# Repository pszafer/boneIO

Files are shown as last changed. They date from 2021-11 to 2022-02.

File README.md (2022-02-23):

# Project description

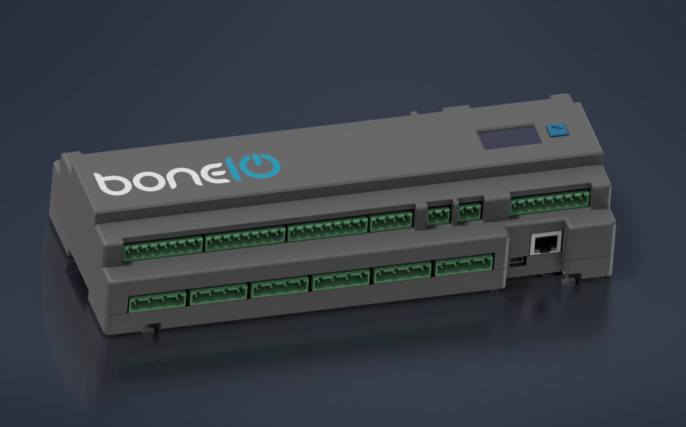
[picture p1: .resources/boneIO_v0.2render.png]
BonePic


`BoneIO` is a compact IO controller for home automation. Main features of this controller are

- Compact size (27x11x6)cm - 15 DIN modules
- DIN rail compatibility
- Low price
- Open HSP (See below)

## Whole documentation you will find here: https://boneio.eu/

## Case, Circuit and Code was moved into separate repositories. You can find it here: https://github.com/boneIO-eu

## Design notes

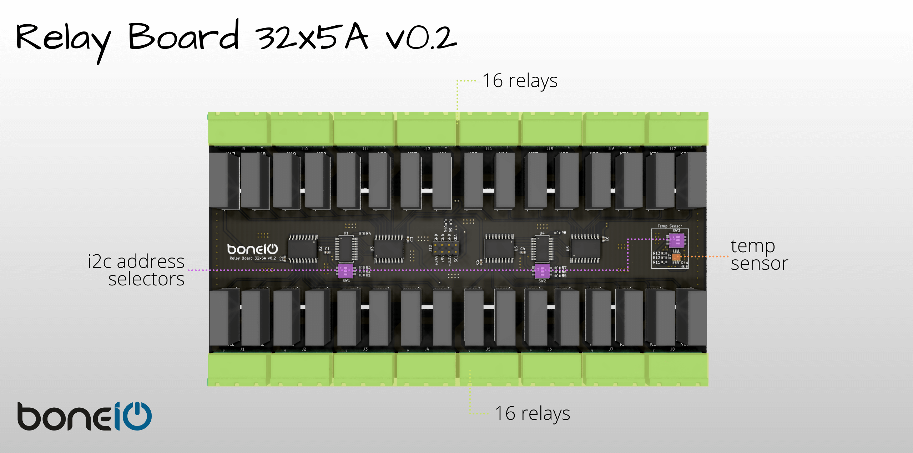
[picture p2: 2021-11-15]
.resources/relay_board_32x5A_text.png

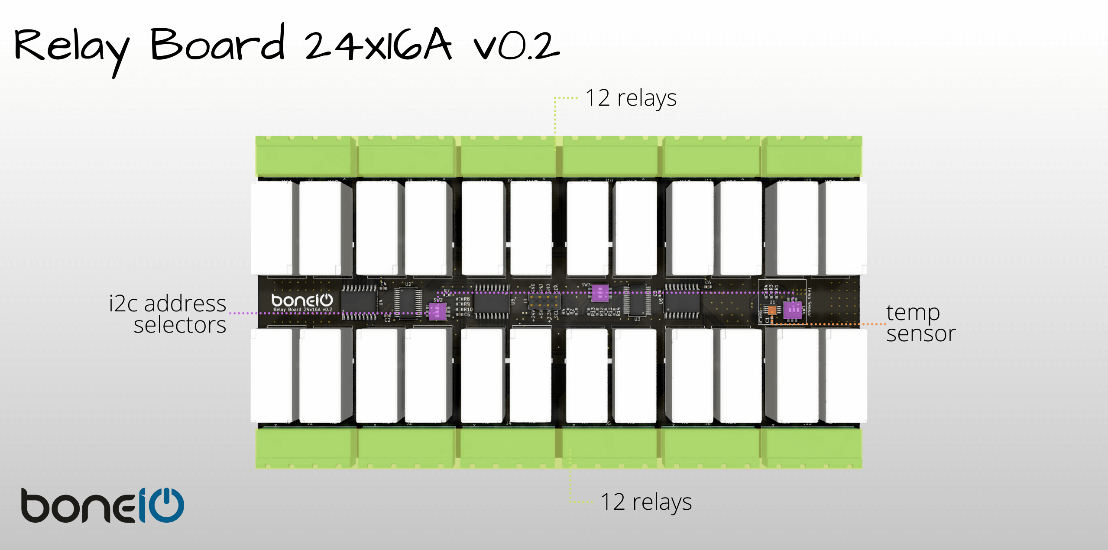
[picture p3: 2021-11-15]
.resources/relay_board_24x16A_text.png

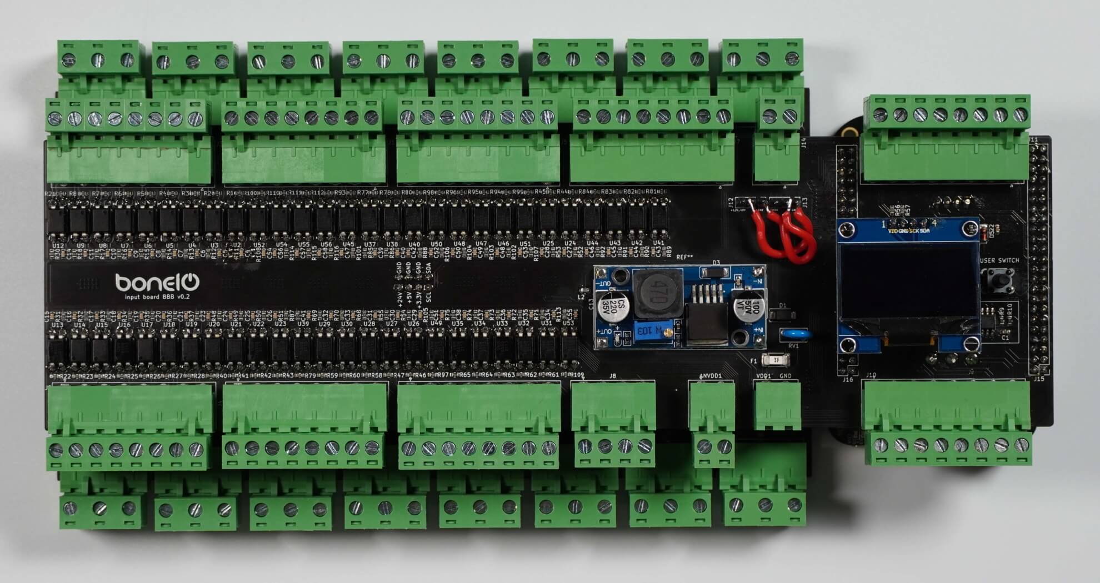
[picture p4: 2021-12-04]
.resources/boneIO_v0.2_full_without_case.jpg

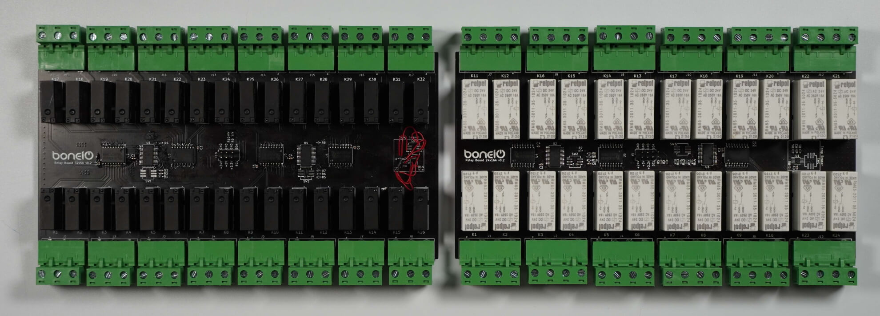
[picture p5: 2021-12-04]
.resources/boneIO_v0.2_relays.jpg

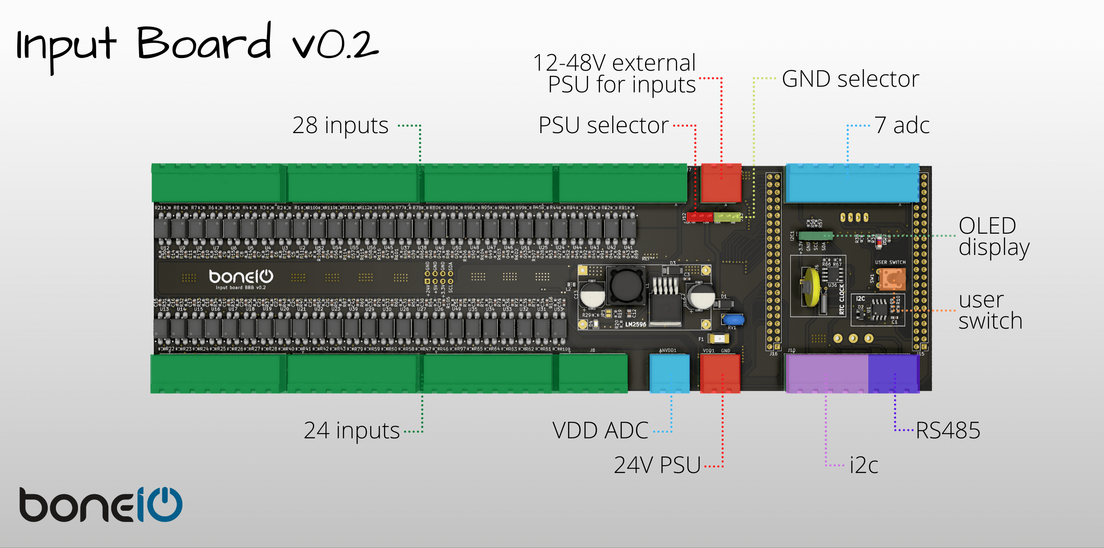
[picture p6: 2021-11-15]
.resources/input_board_text.png

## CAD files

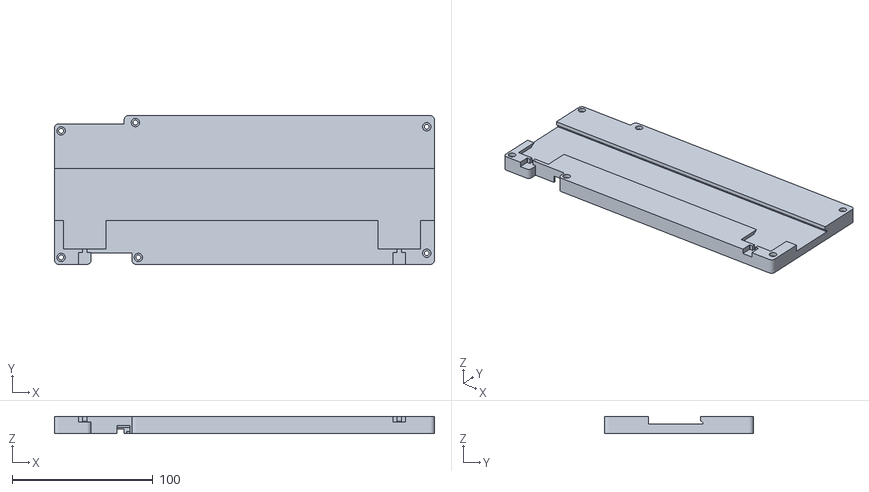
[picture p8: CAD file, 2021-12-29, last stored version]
Case/case_back.stl
270.0 x 105.8 x 12.3

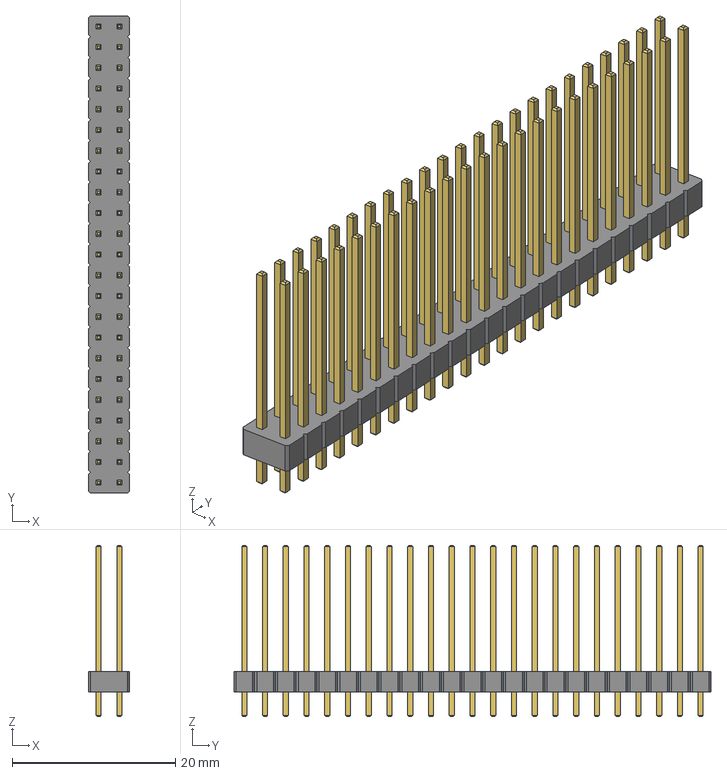
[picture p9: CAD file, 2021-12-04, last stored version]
Circuit/boneIO - input board_BBB/3D_model/46_pin.stp
5.08 x 58.4 x 21.0 mm

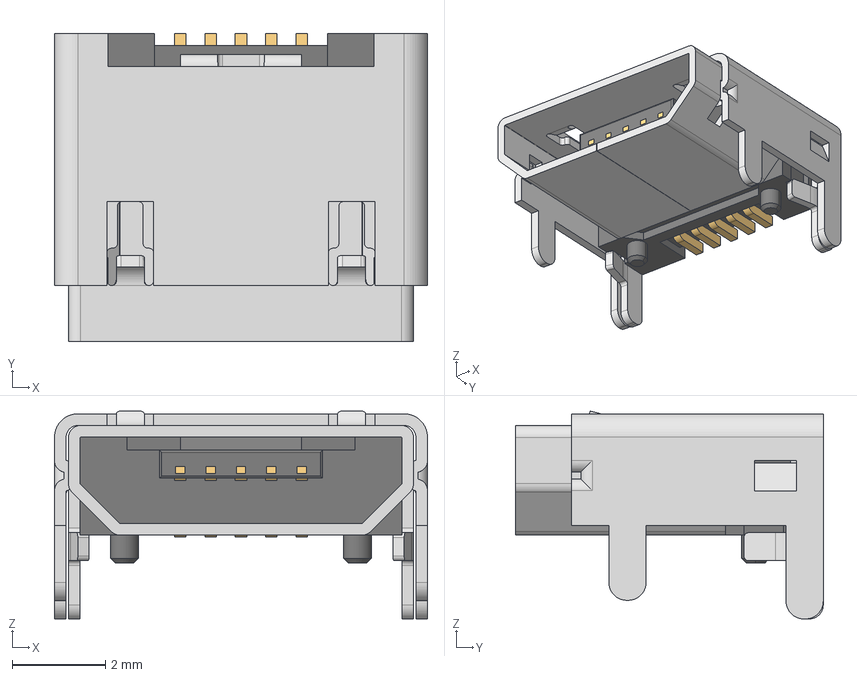
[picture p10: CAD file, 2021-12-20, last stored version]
Circuit/boneIO - input board_ESP/3D/usb_micro_4p.stp
8.00 x 6.60 x 4.46 mm

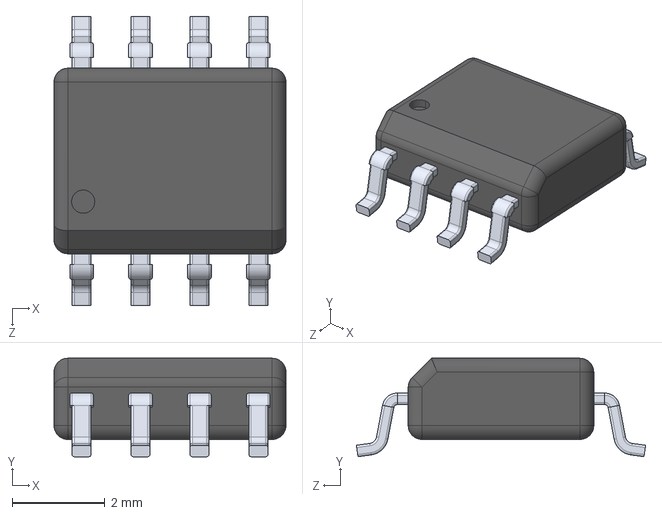
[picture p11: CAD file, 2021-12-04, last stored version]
Circuit/boneIO - relay board 24x10A/3D_model/SO8.STEP
5.00 x 2.12 x 6.23 mm

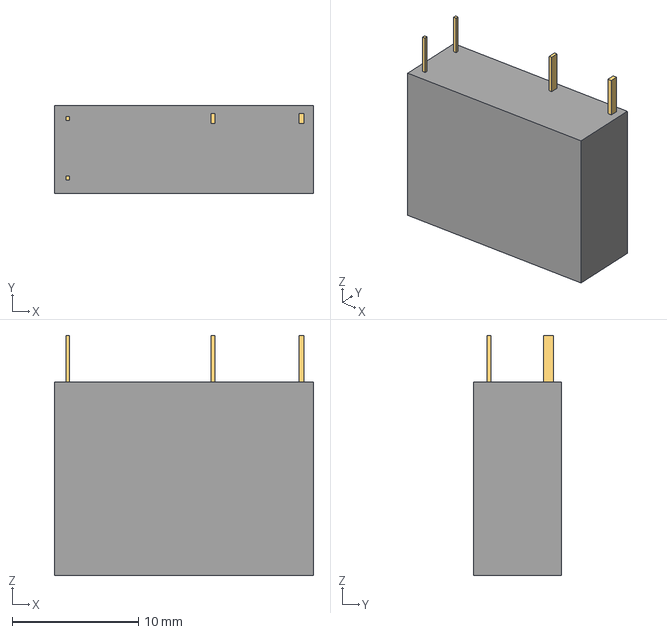
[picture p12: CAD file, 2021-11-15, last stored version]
Circuit/boneIO - relay board 32x5A/HF46/HF46F.step
20.5 x 7.00 x 19.0 mm

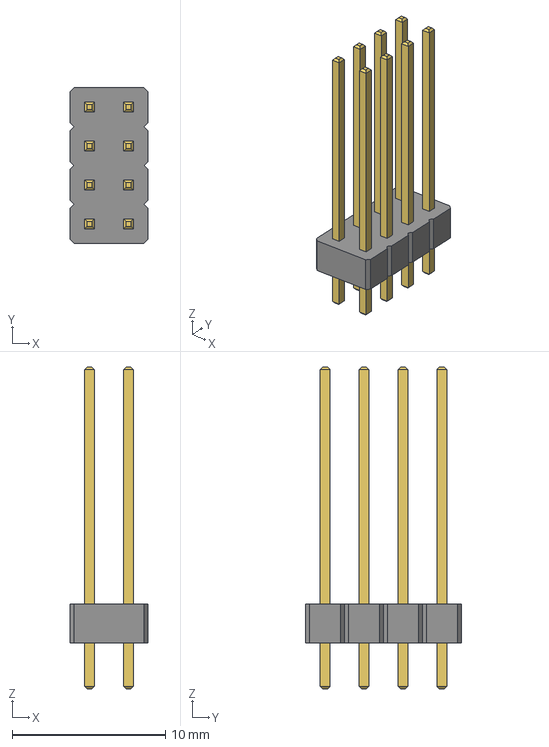
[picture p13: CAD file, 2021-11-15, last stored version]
Circuit/boneIO - relay board 32x5A/PH80DS-21/PH80DS-21.stp
5.08 x 10.2 x 21.0 mm

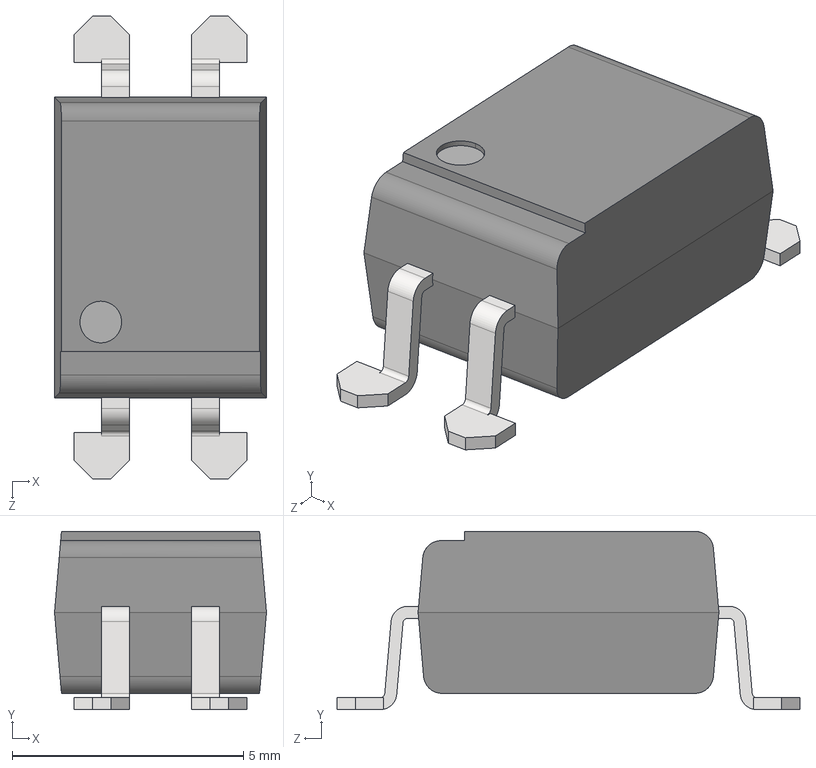
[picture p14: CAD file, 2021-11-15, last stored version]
Circuit/boneIO - shield input board v0.2/3D_model/PC817.STEP
4.58 x 3.85 x 10.0 mm
PC817 Body
Gullwing Pin
Gullwing Pin_MIR
Gullwing Pin_MIR1
Gullwing Pin_MIR_MIR

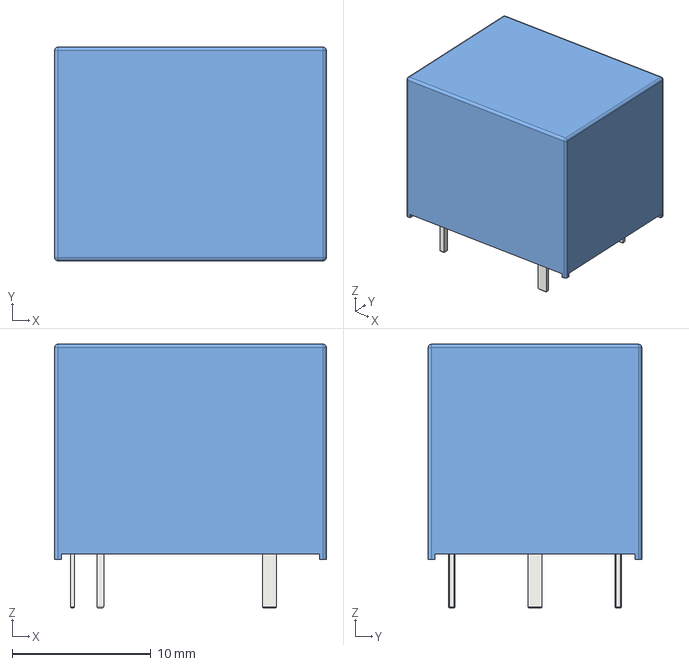
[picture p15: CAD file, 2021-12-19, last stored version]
Circuit/boneIO - shutter board 32x10A/3d_Model/Relay_SPDT_SANYOU_SRD_Series_Form_C.step
19.6 x 15.4 x 19.0 mm

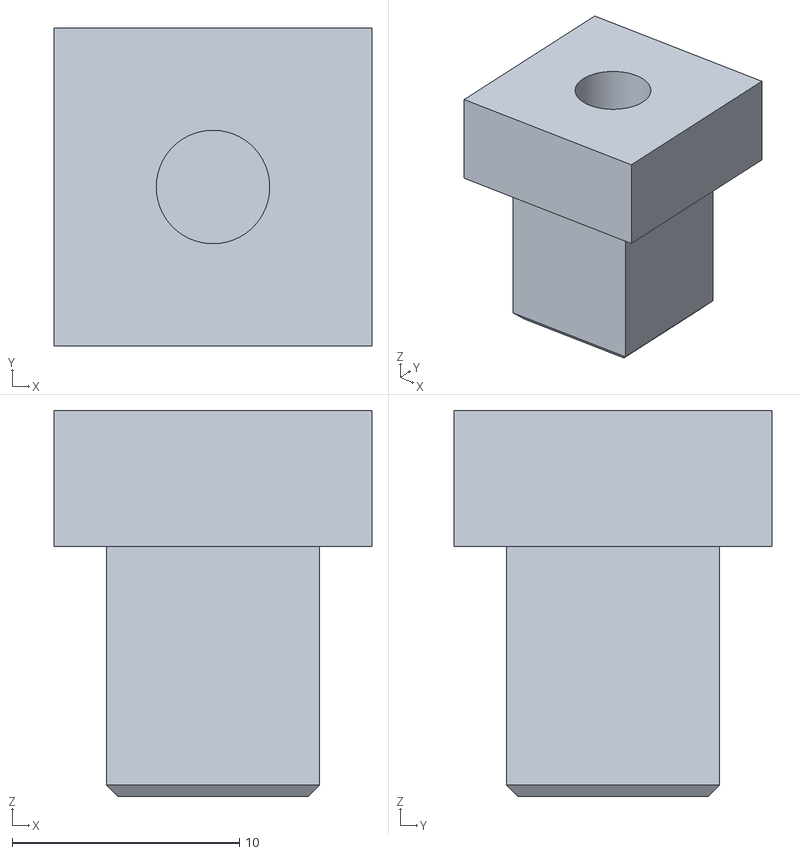
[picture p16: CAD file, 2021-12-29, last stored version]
Case/button.stl
14.0 x 14.0 x 17.0

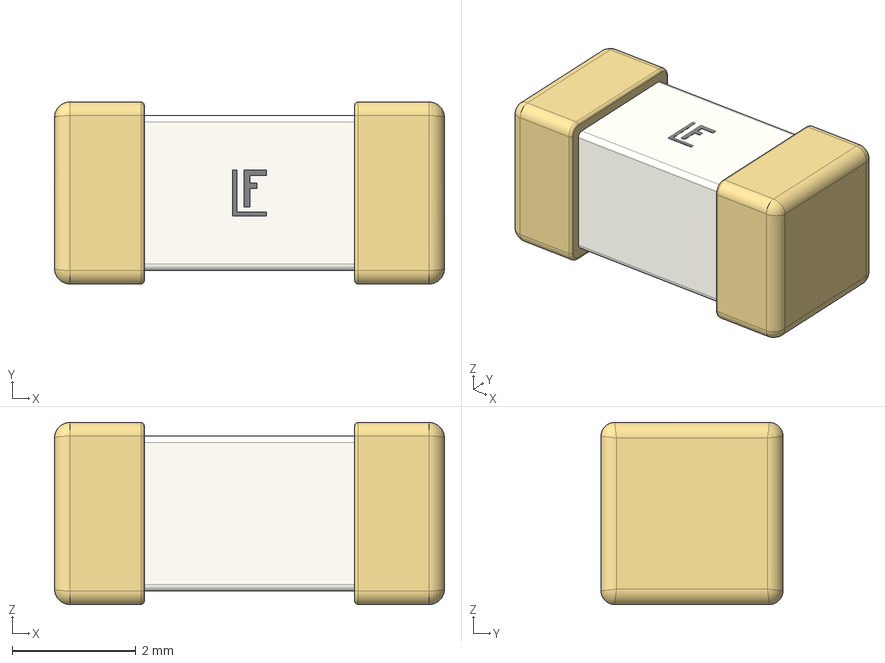
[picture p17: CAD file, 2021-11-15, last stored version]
Circuit/boneIO - input board_BBB/3D_model/FUSE LTL-451.stp
6.30 x 2.94 x 2.94 mm

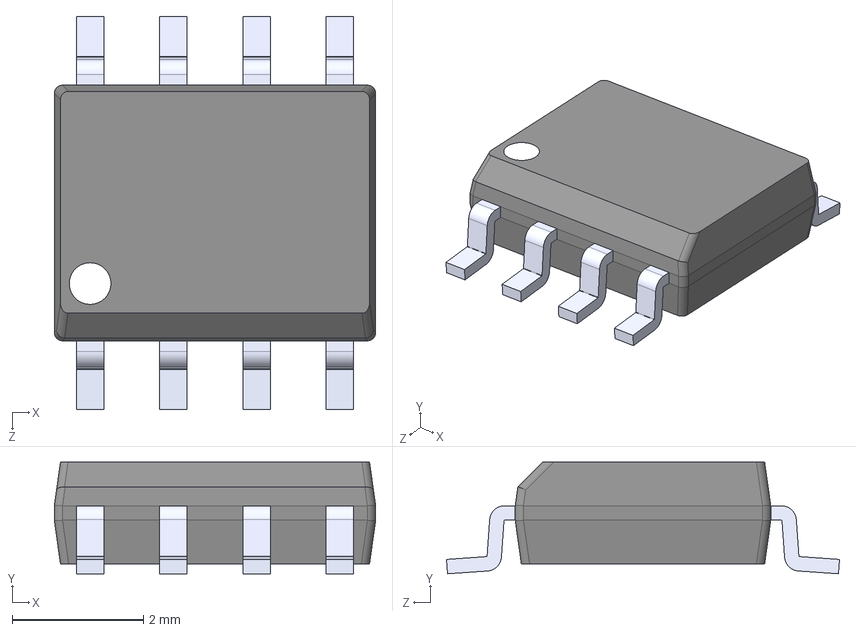
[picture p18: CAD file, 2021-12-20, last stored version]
Circuit/boneIO - input board_ESP/3D/MP1584EN.step
4.90 x 1.70 x 5.99 mm

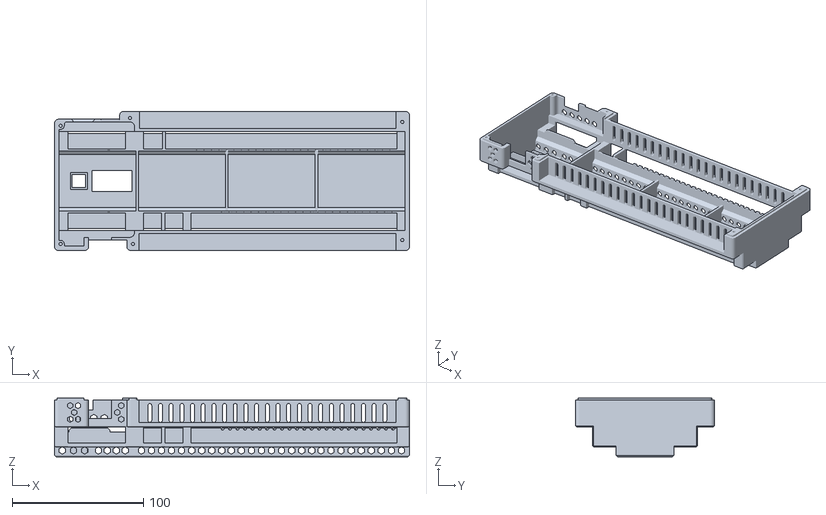
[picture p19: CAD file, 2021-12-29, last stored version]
Case/case_front.stl
270.0 x 105.8 x 44.5

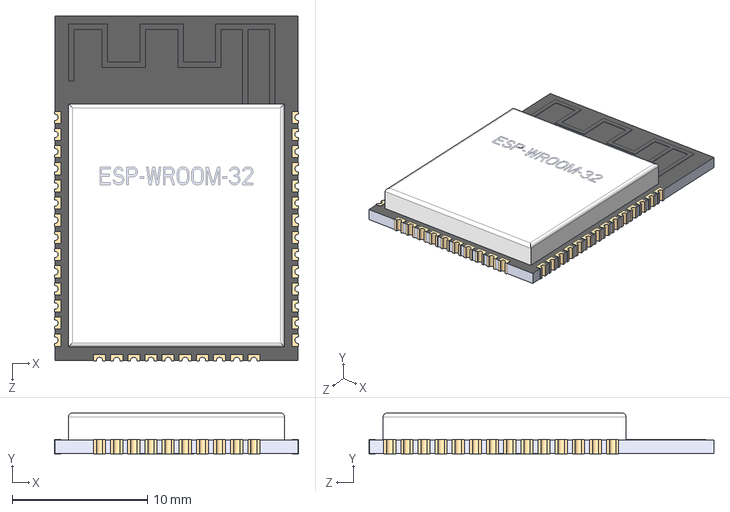
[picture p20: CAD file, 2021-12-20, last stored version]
Circuit/boneIO - input board_ESP/3D/esp-wroom-32.step
18.1 x 3.04 x 25.5 mm

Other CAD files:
Case/boneIO-bottom-clips.stl
Case/boneIO-button-distance-relay-24x16A.stp
Case/boneIO-button-distance-relay-32x5A.stp
Case/boneIO-button.stl
Case/boneIO-case-front.stl
Case/boneIO-case_back.stl
Case/boneIO-case_front.stl
Case/boneIO-distance-relay-24x16.stl
Case/boneIO-distance-relay-32x5.stl
Case/boneIO-lock-pin.stl
Case/clips.stl
Case/lock_pin.stl
Case/spacer_relay_24x16A.stl
Case/spacer_relay_32x5A.stl
Circuit/boneIO - input board/3D_model/CR1220_VCNK.stp
Circuit/boneIO - input board_BBB/3D_model/CR1220_VCNK.stp
Circuit/boneIO - input board_ESP/3D/Connector_1Port_RJ45.step
Circuit/boneIO - input board_ESP/3D/ESP32.STEP
Circuit/boneIO - relay board 24x10A/3D_model/RM852011351005_1.step
Circuit/boneIO - relay board 24x16A/3D_model/RM852011351005_1.step

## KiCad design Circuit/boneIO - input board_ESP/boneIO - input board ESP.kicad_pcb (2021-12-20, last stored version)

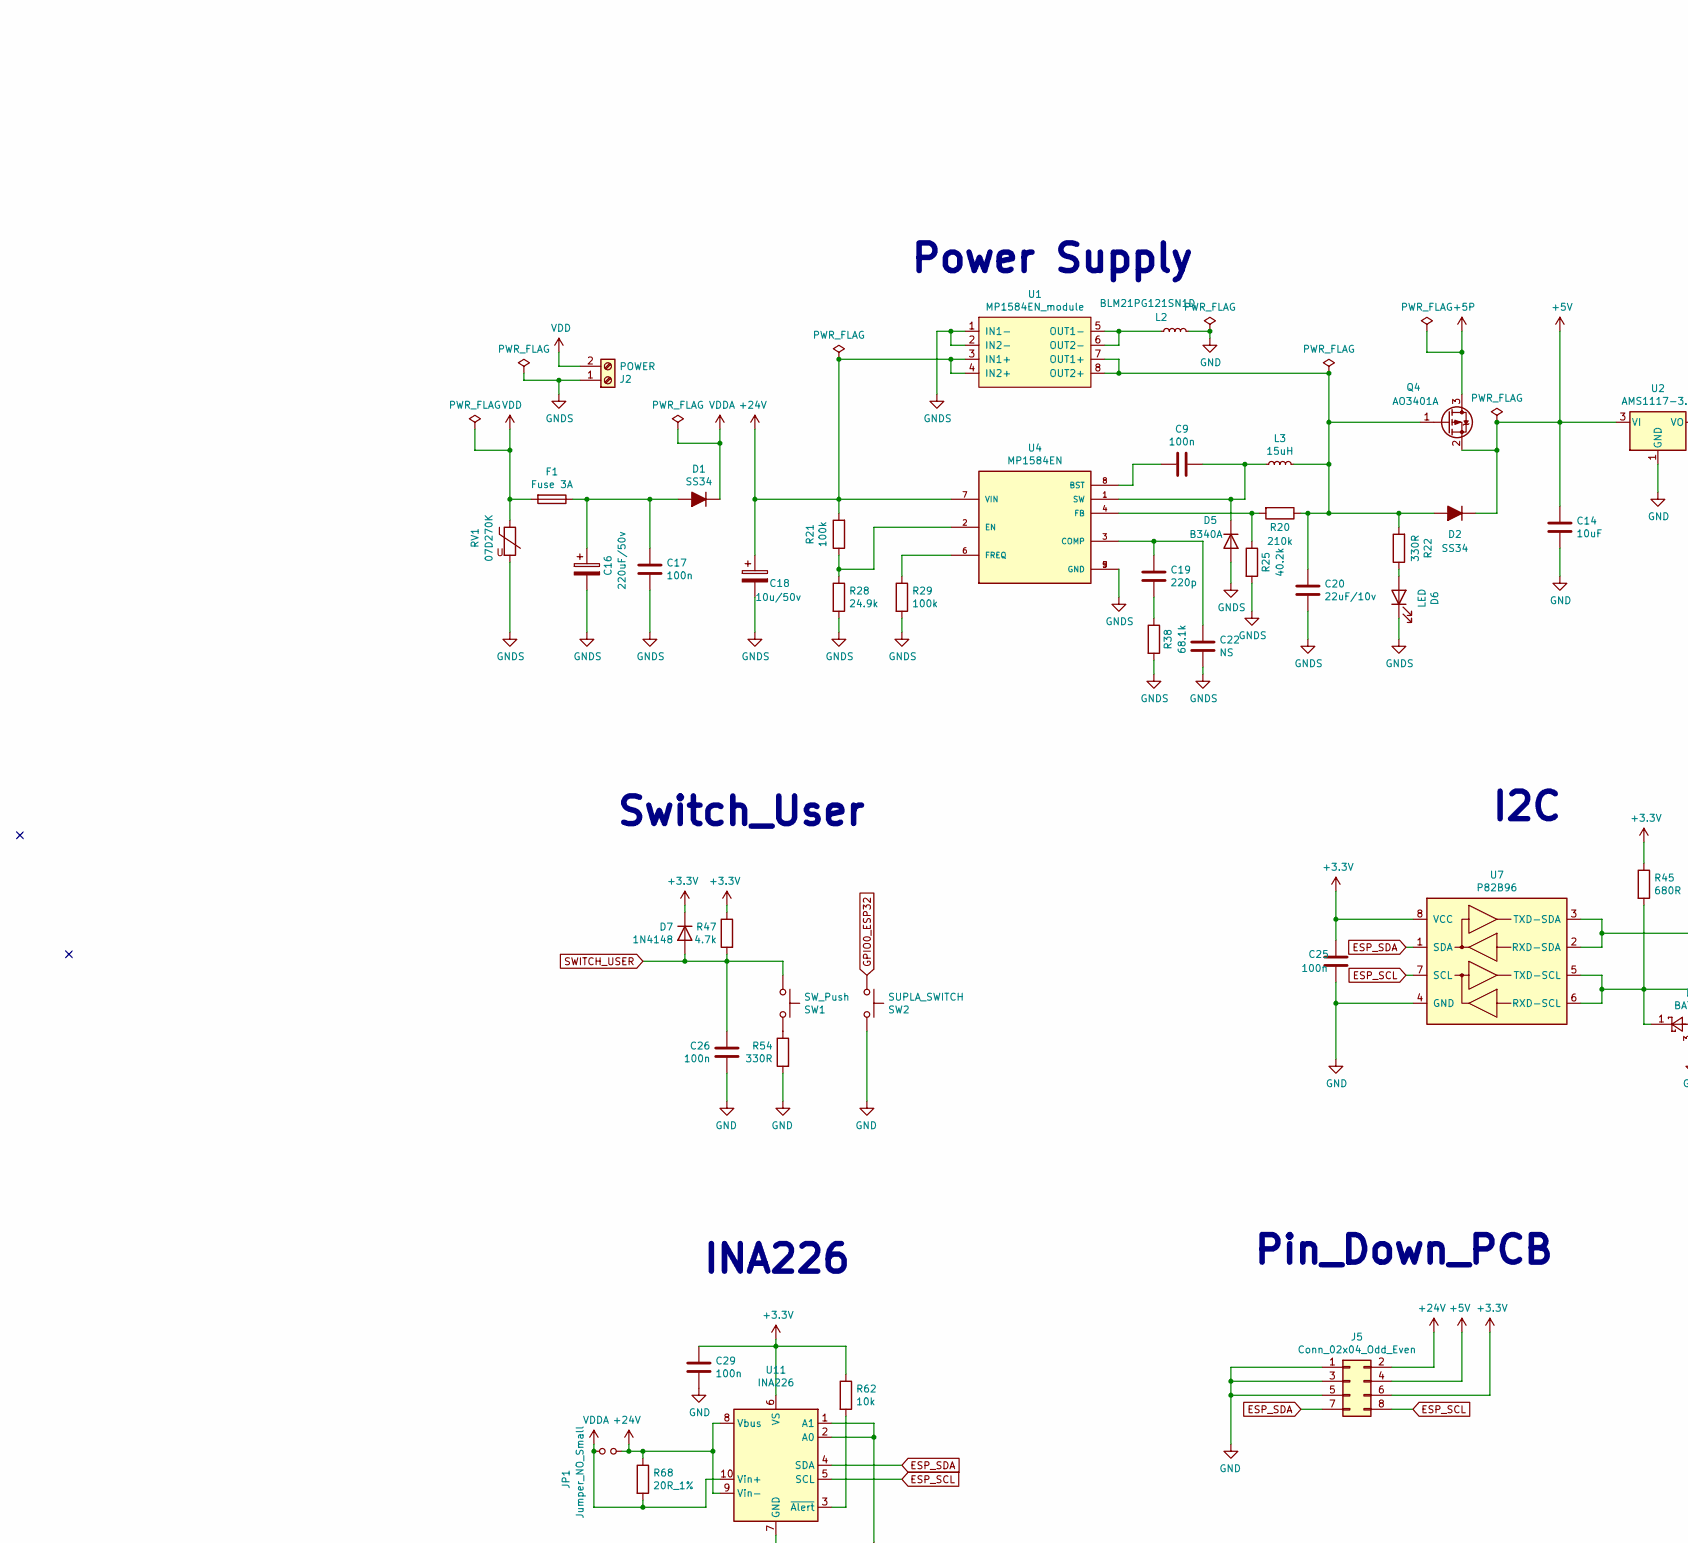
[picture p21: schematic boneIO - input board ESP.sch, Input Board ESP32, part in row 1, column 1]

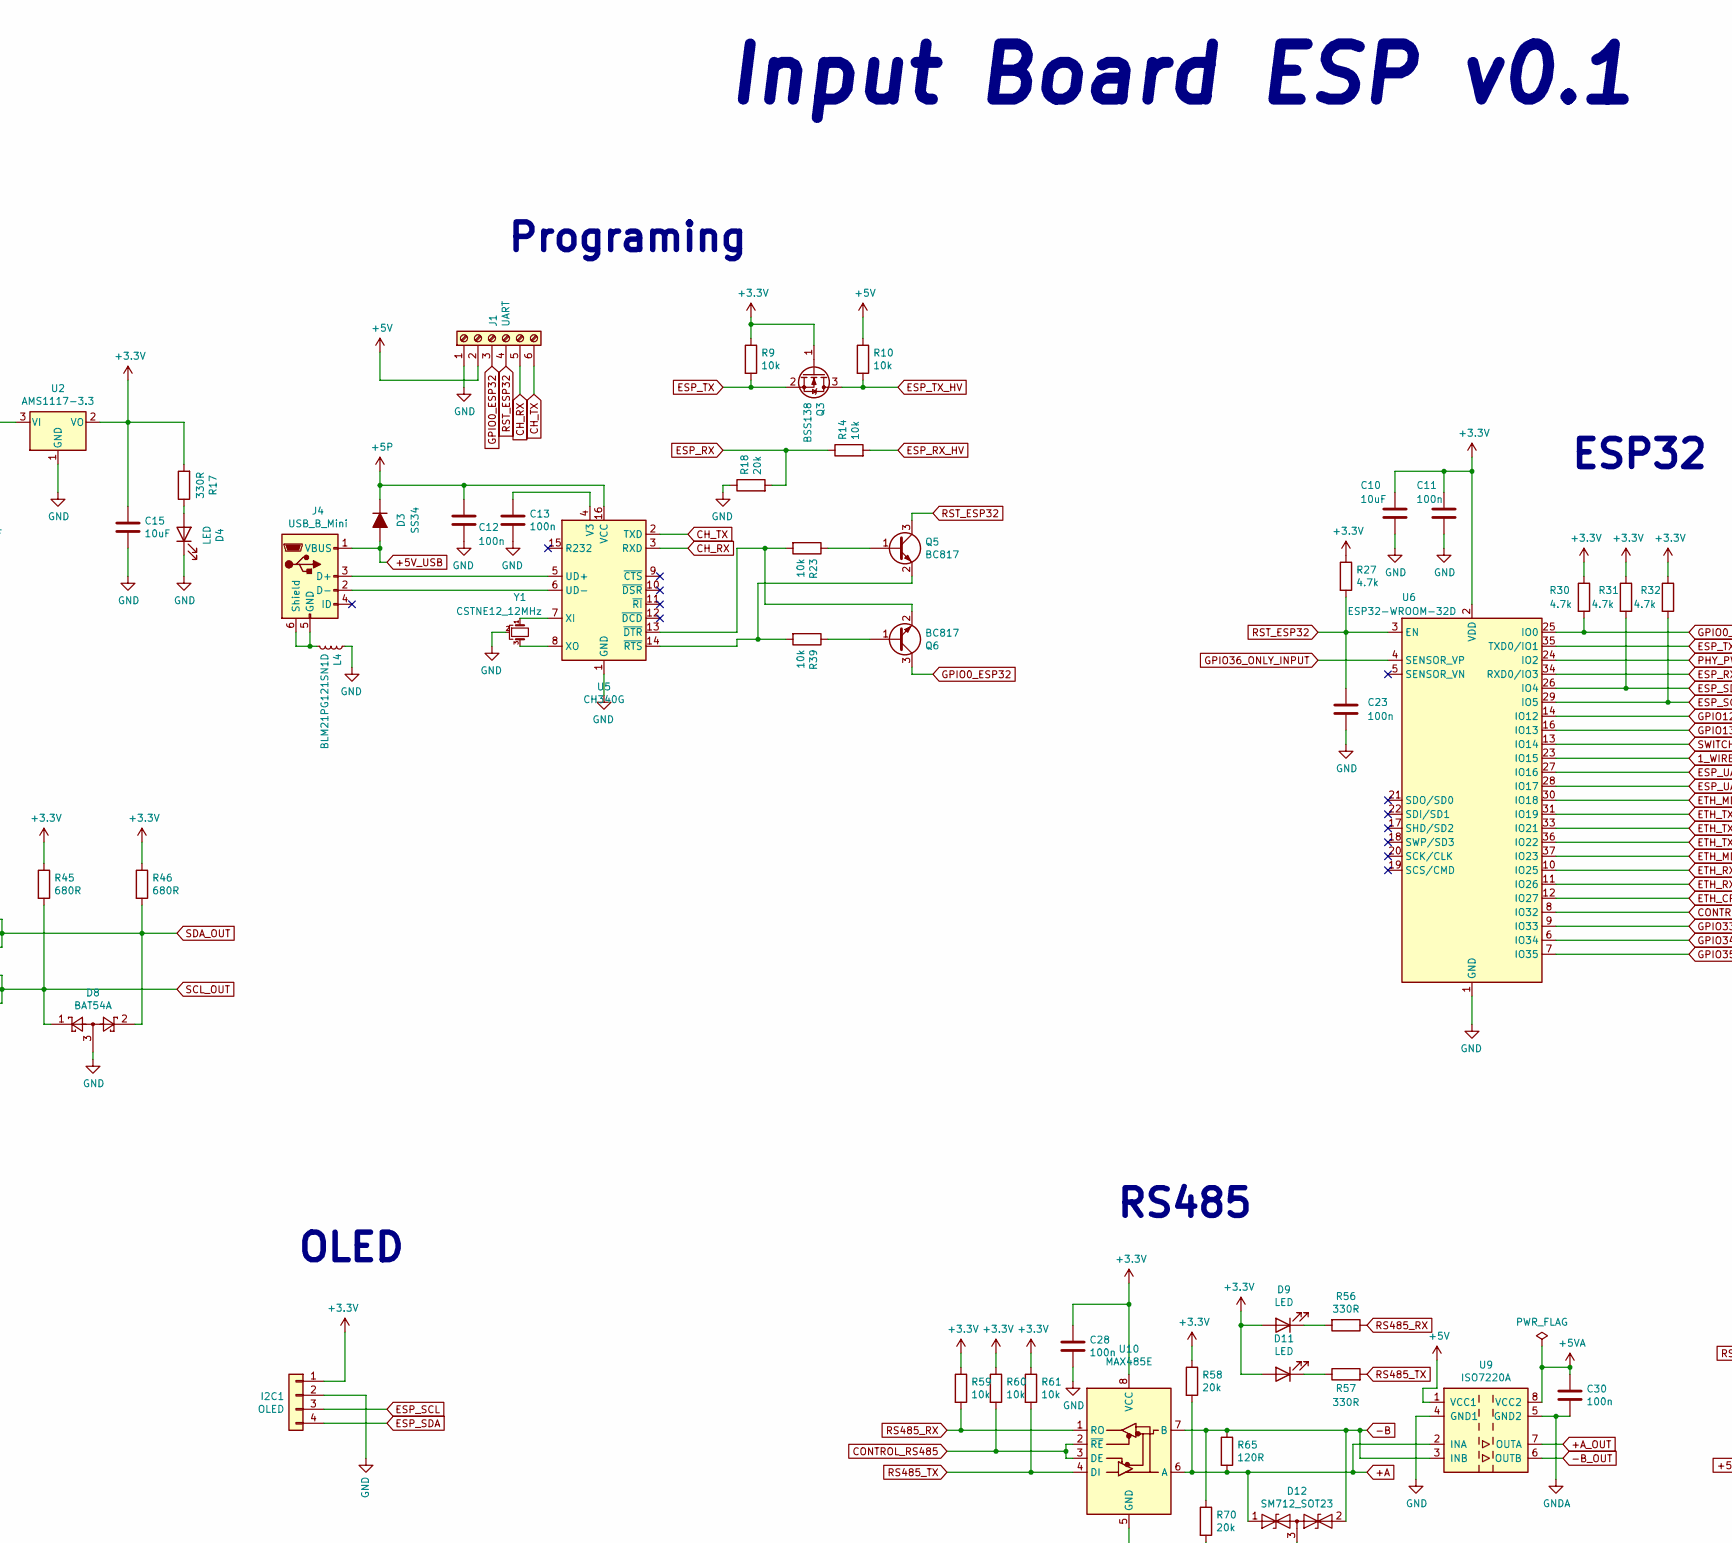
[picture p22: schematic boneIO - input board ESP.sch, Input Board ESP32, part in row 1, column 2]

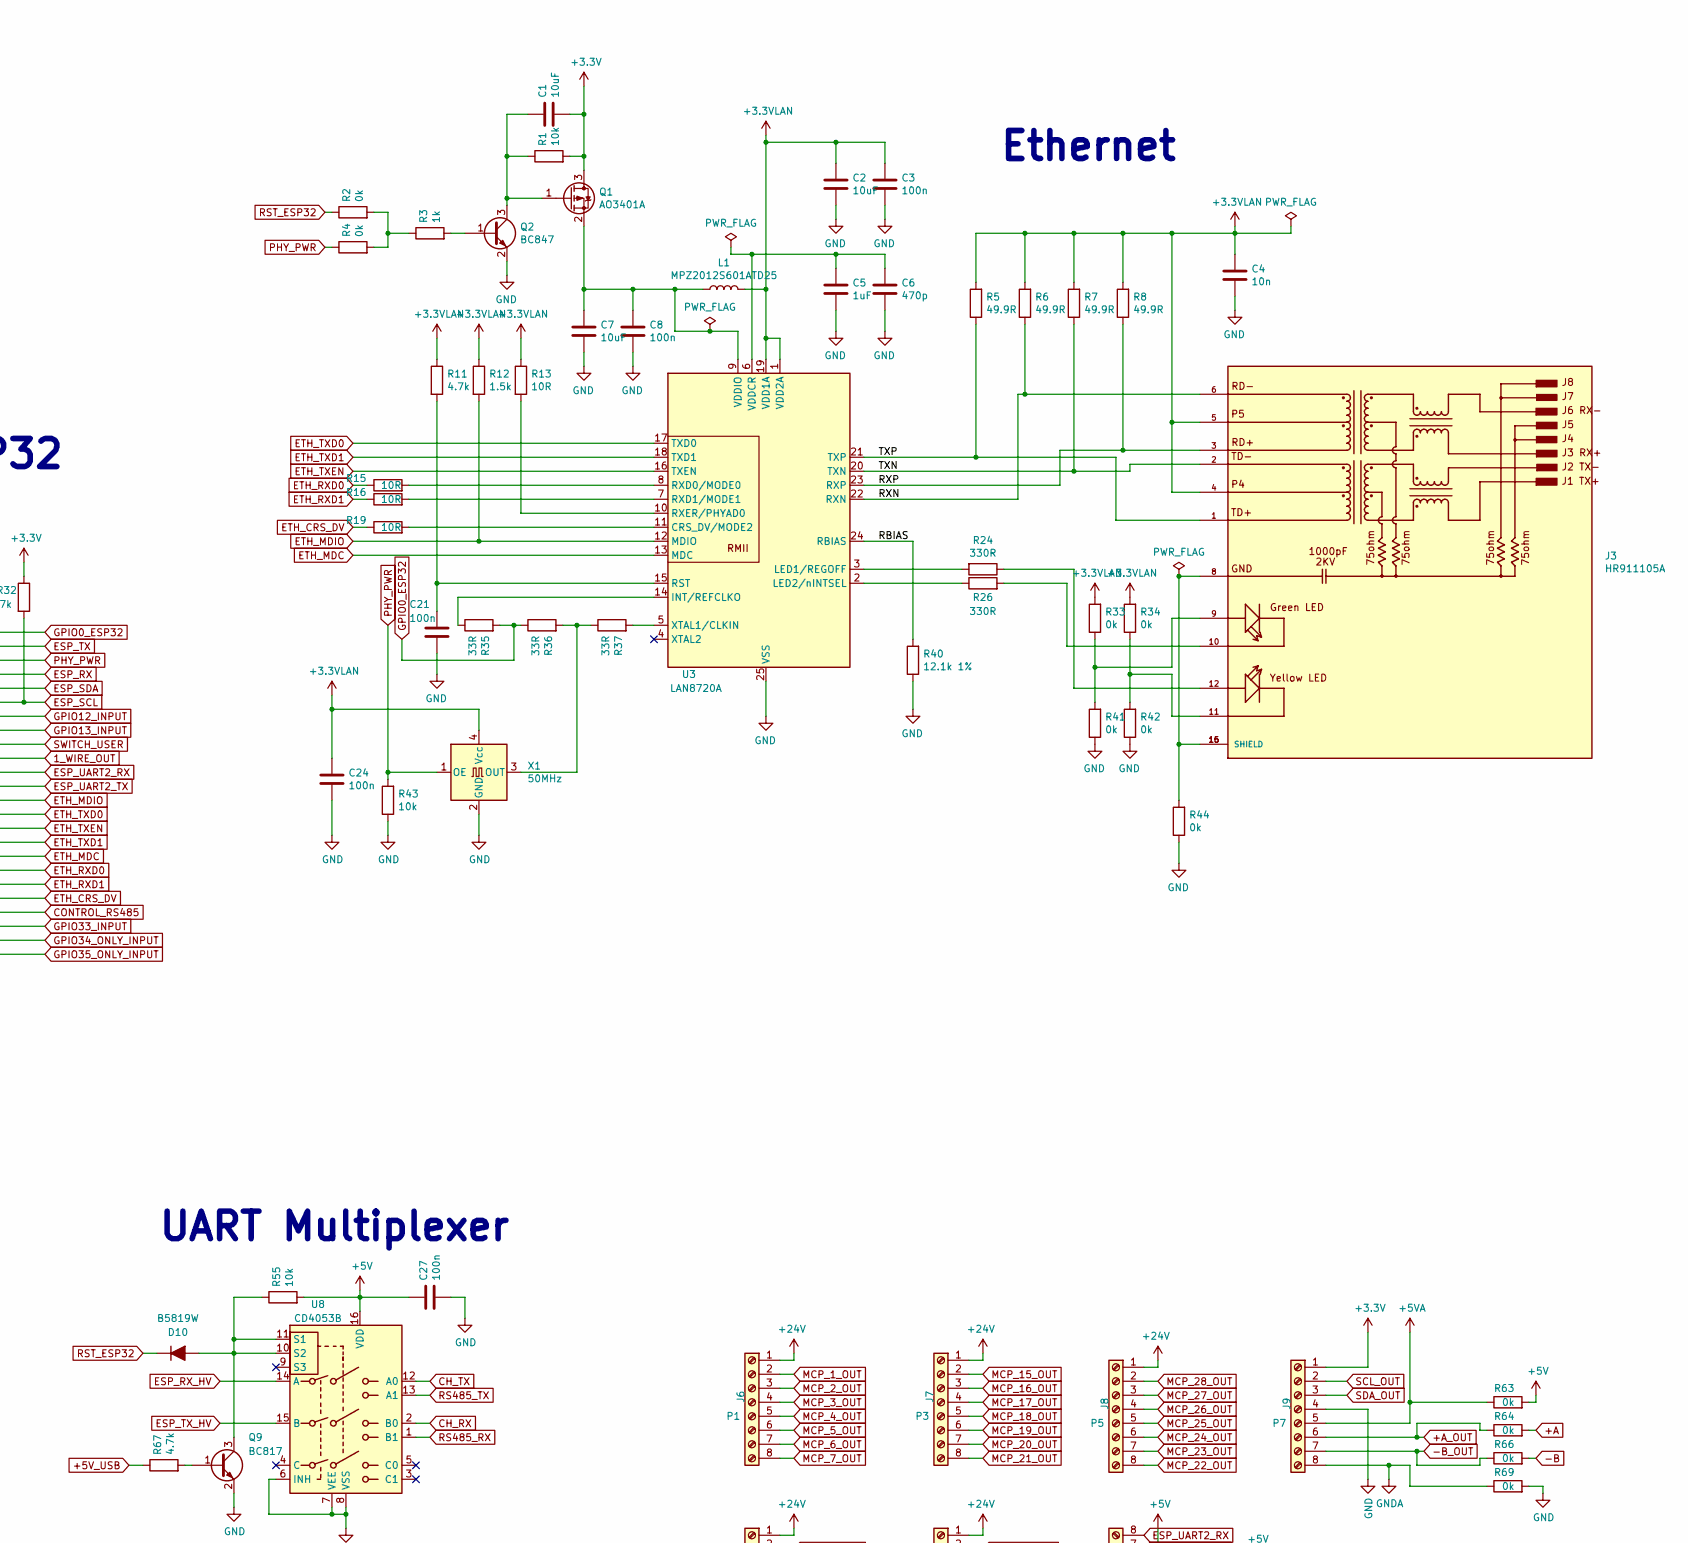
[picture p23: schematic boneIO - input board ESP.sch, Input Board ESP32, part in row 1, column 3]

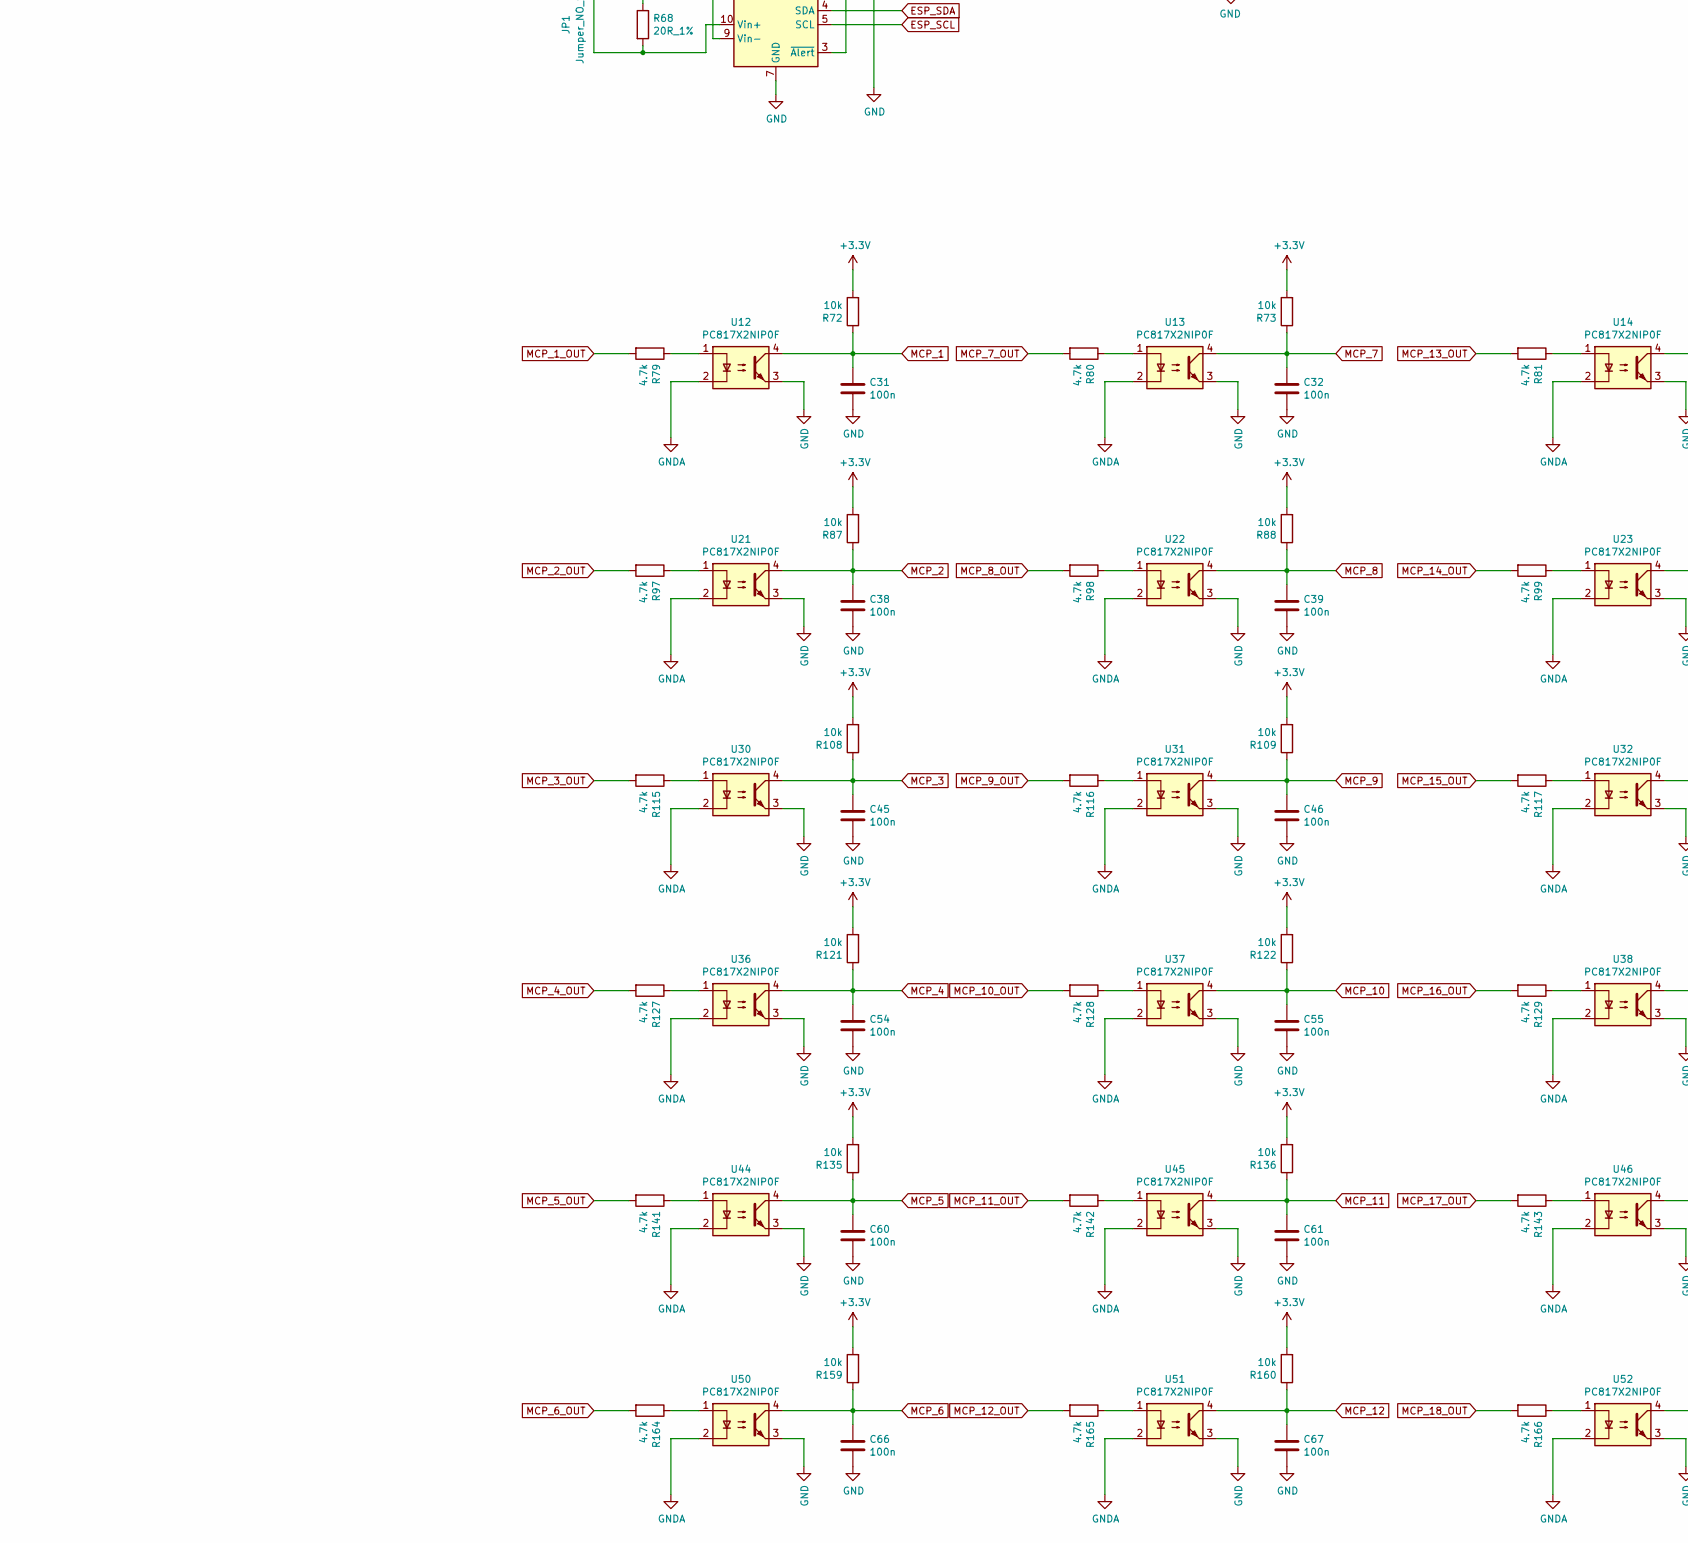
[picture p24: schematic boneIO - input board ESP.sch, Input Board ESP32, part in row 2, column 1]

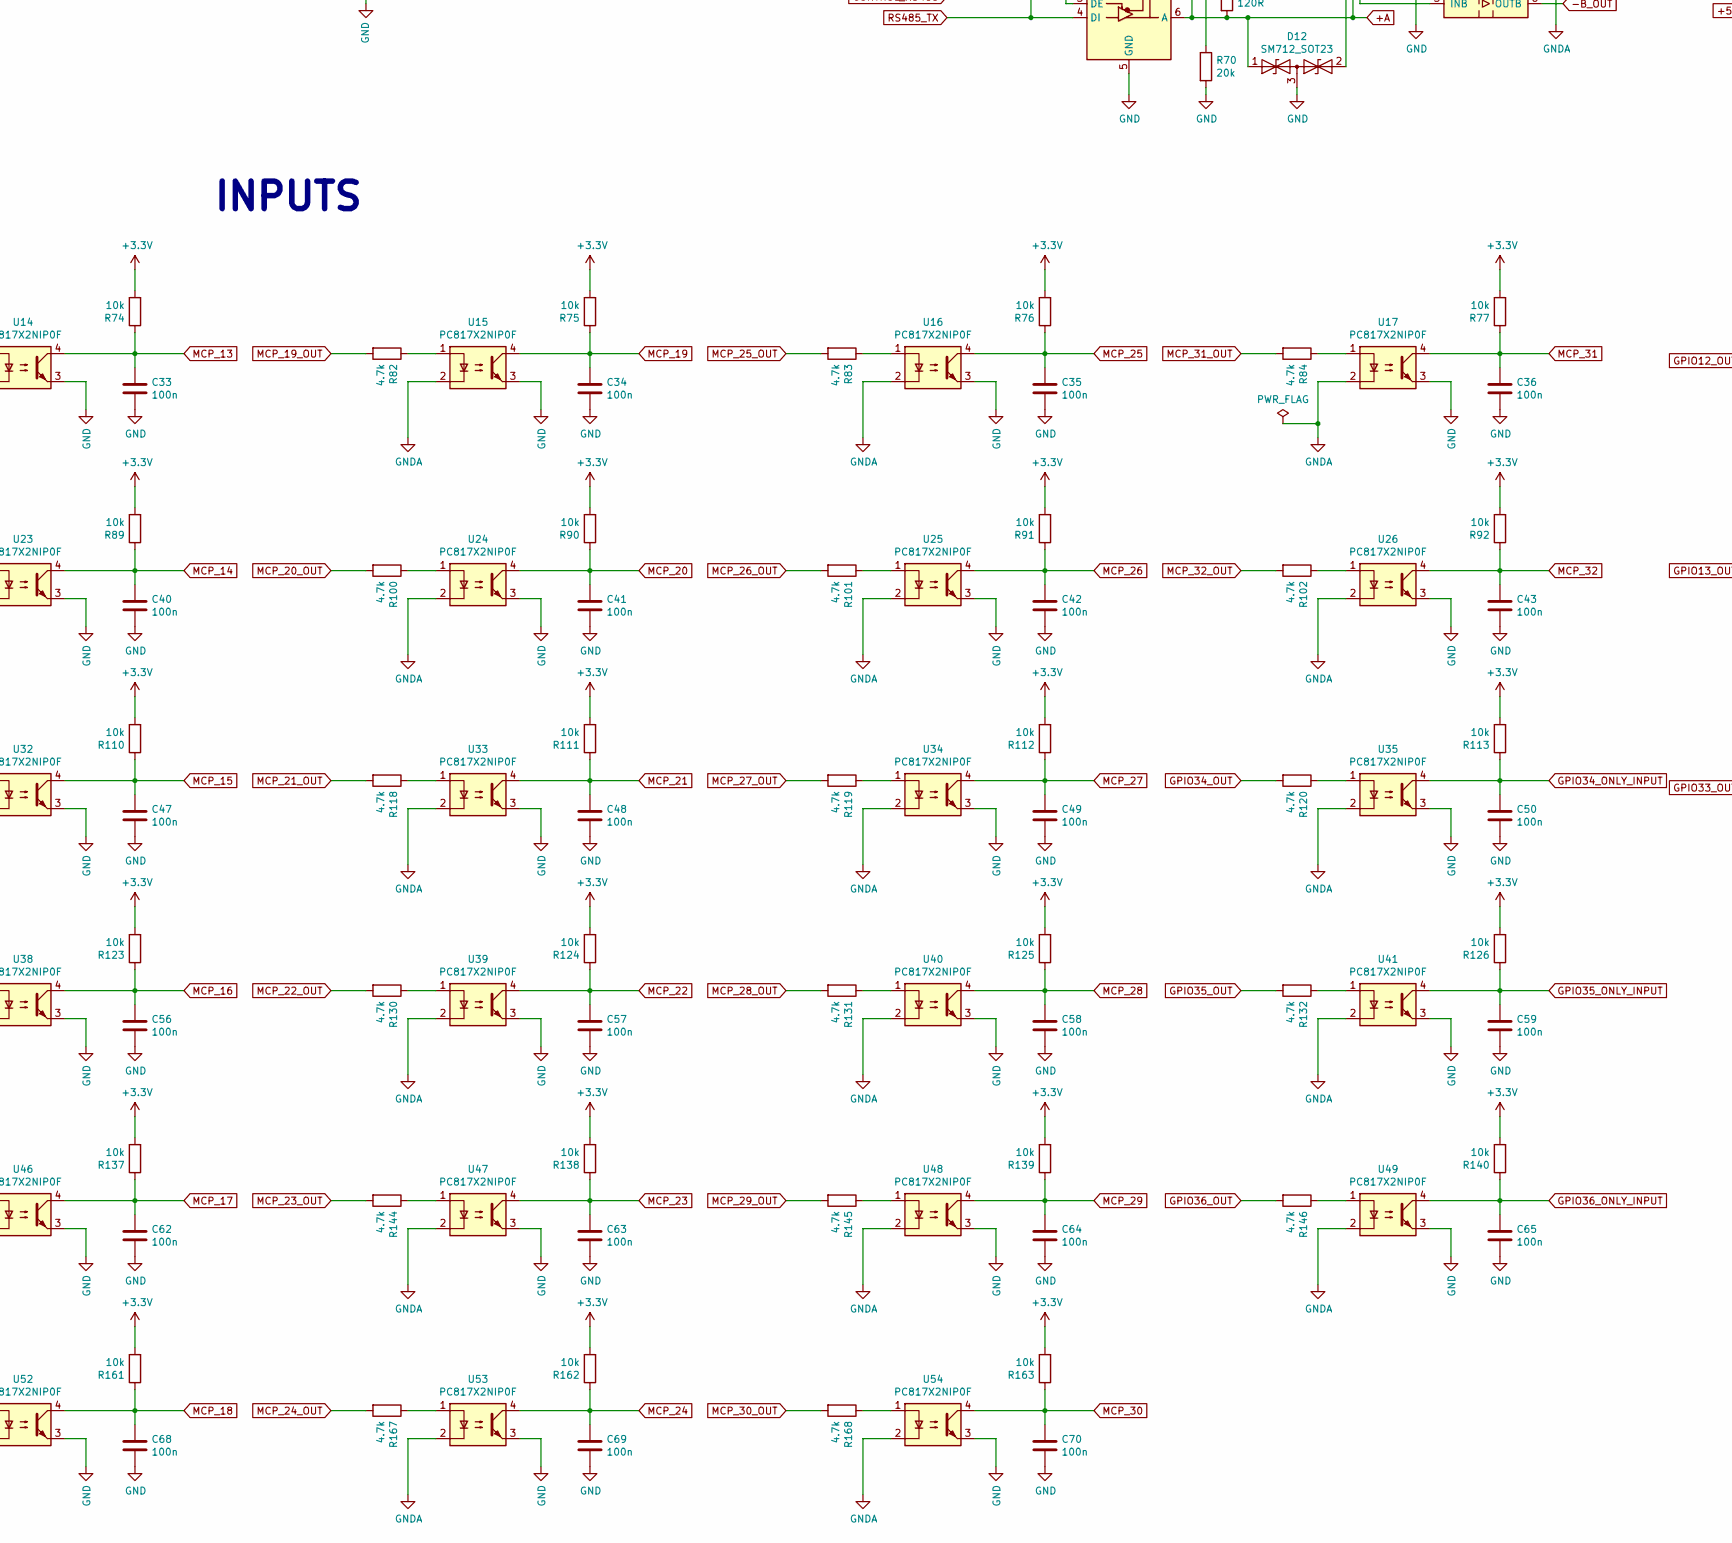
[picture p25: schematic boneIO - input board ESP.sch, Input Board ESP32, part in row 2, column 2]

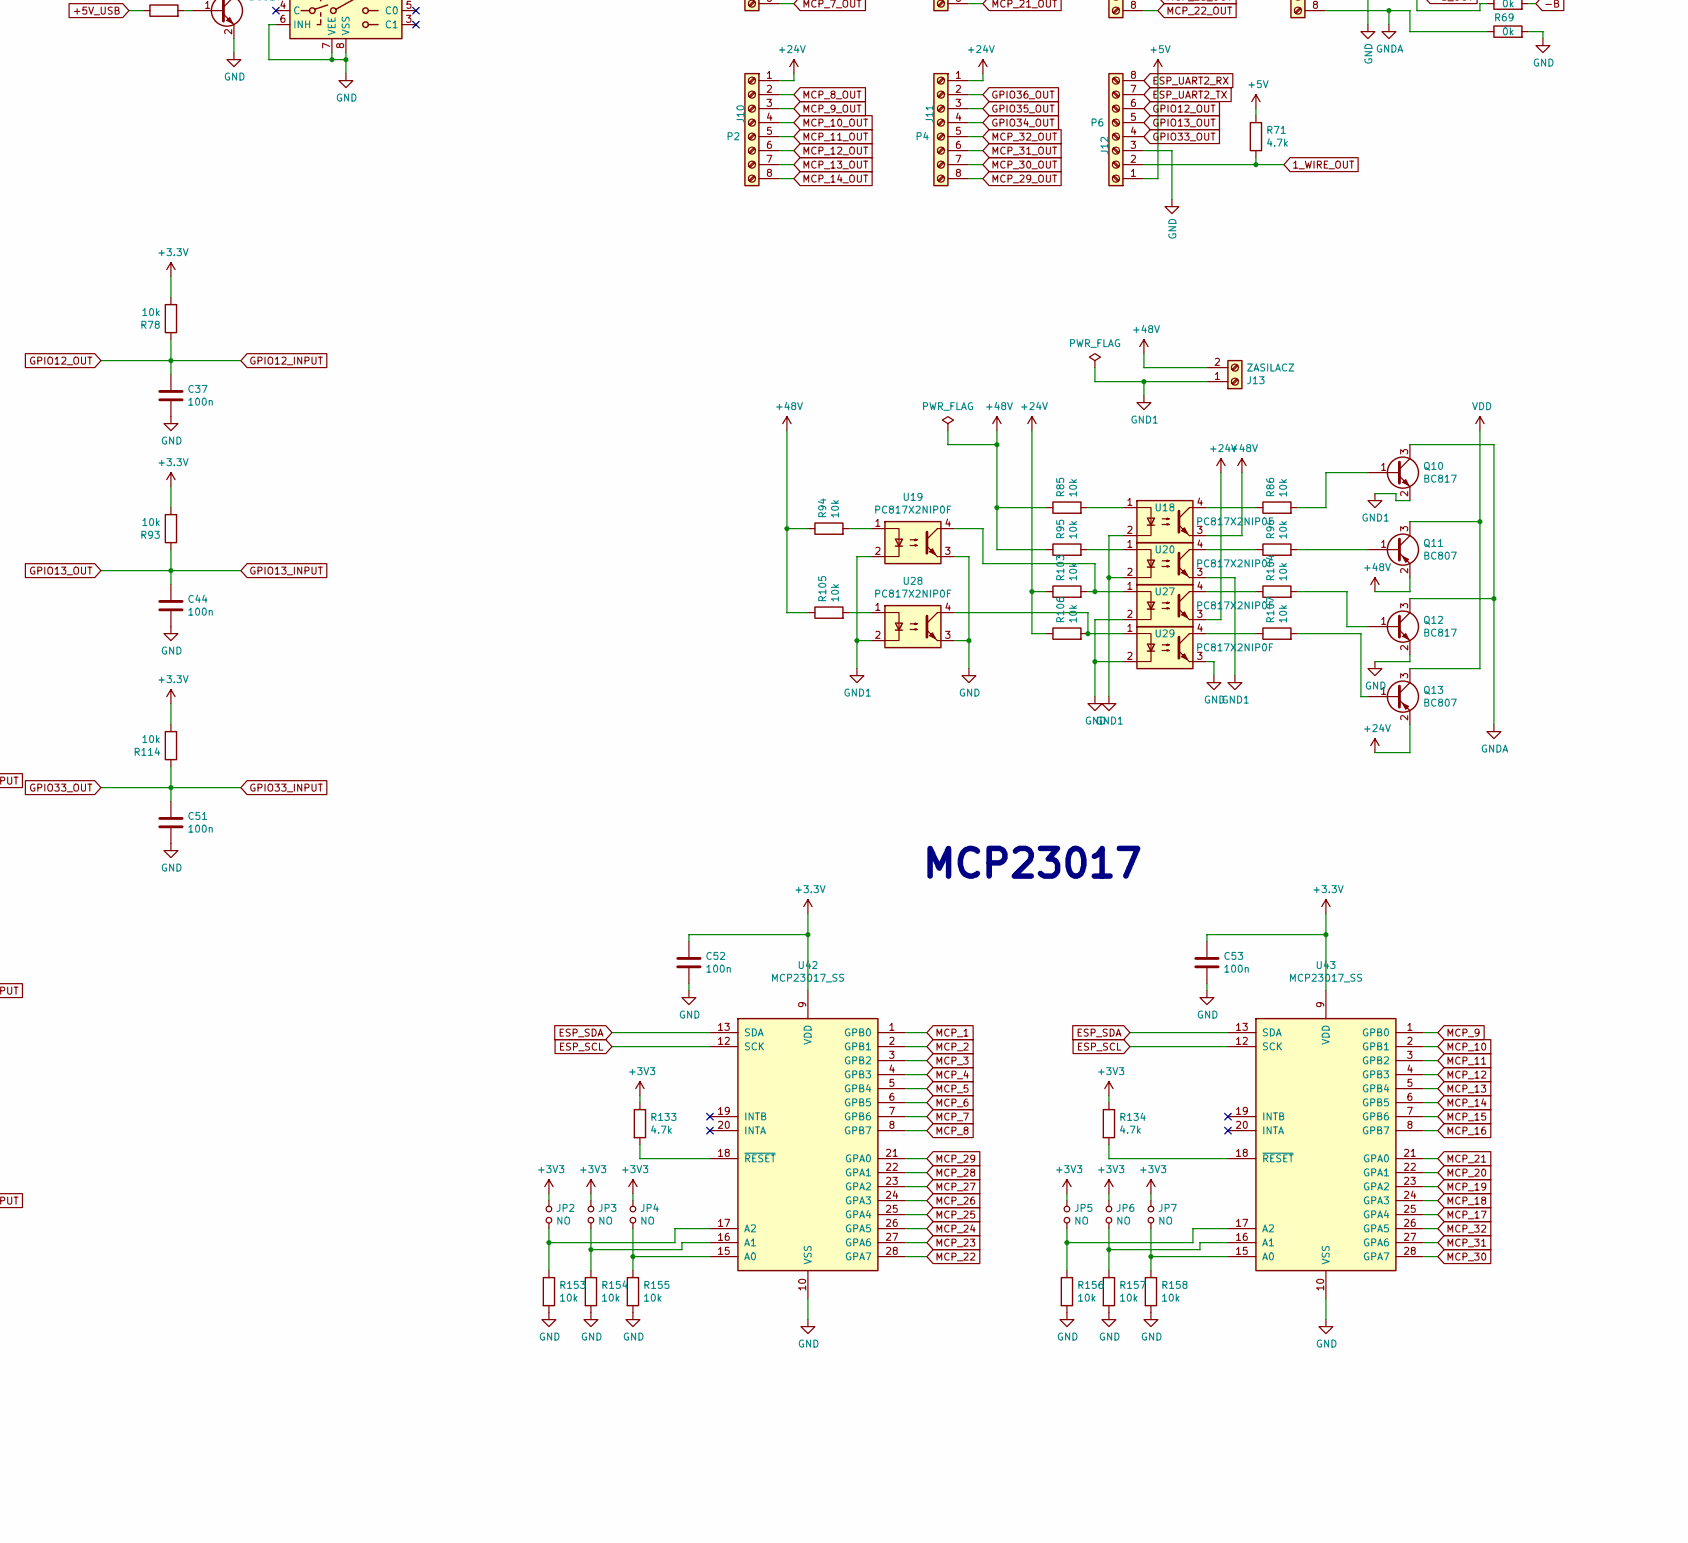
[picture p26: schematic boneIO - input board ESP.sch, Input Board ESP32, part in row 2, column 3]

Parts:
C1, C2, C7, C10, C14, C15: 10uF; C_0805_2012Metric
C3, C8, C11, C12, C13, C17, C21, C23, C24, C27, C28, C29, C30, C52, C53: 100n; C_0603_1608Metric
C4: 10n; C_0805_2012Metric
C5: 1uF; C_0805_2012Metric
C6: 470p; C_0603_1608Metric
C9: 100n; C_0805_2012Metric
C16: 220uF/50v; CP_Elec_8x10
C18: 10u/50v; C_1206_3216Metric
C19: 220p; C_0603_1608Metric
C20: 22uF/10v; C_1206_3216Metric
C22: NS; C_0805_2012Metric
C25, C26, C31, C32, C33, C34, C35, C36, C37, C38, C39, C40, C41, C42, C43, C44, C45, C46, C47, C48, C49, C50, C51, C54, C55, C56, C57, C58, C59, C60, C61, C62, C63, C64, C65, C66, C67, C68, C69, C70: 100n; C_0603_1608Metric; JLCPCB C14663
D1: SS34; D_SMA; JLCPCB C64982
D2, D3: SS34; D_SOD-323_HandSoldering; JLCPCB C64982
D4, D6, D9, D11: LED; C_0805_2012Metric
D5: B340A; D_SMA
D7: 1N4148; D_MiniMELF; JLCPCB C68883
D8: BAT54A; SOT-23; JLCPCB C466636
D10: B5819W; D_SMA; JLCPCB C64982
D12: SM712_SOT23; SOT-23
F1: Fuse 3A; Fuse_2512_6332Metric
I2C1: OLED; PinSocket_1x04_P2.54mm_Vertical
J1: UART; PinHeader_1x06_P2.00mm_Vertical
J2: POWER; pin2
J3: HR911105A; HANRUN_HR911105A; PARTREV A
J4: USB_B_Mini; USB_Mini-B_Wuerth_65100516121_Horizontal
J5: Conn_02x04_Odd_Even; PinHeader_2x04_P2.54mm_Vertical
J6: P1; pin8
J7: P3; pin8
J8: P5; pin8
J9: P7; pin8
J10: P2; pin8
J11: P4; pin8
J12: P6; pin8
J13: ZASILACZ; pin2
JP1: Jumper_NO_Small; SolderJumper-2_P1.3mm_Open_RoundedPad1.0x1.5mm
JP2, JP3, JP4, JP5, JP6, JP7: NO; SolderJumper-2_P1.3mm_Open_RoundedPad1.0x1.5mm
L1: MPZ2012S601ATD25; L_0805_2012Metric
L2, L4: BLM21PG121SN1D; L_0805_2012Metric
L3: 15uH; L_7.3x7.3_H4.5
Q1, Q4: AO3401A; SOT-23
Q2: BC847; SOT-23
Q3: BSS138; SOT-23
Q5, Q6, Q9, Q10, Q12: BC817; SOT-23
Q11, Q13: BC807; SOT-23
R1, R9, R10, R14, R23, R39, R43, R153, R154, R155, R156, R157, R158: 10k; R_0603_1608Metric
R2, R4, R33, R34, R41, R42, R44, R63, R64, R66, R69: 0k; R_0603_1608Metric
R3: 1k; R_0603_1608Metric
R5, R6, R7, R8: 49.9R; R_0603_1608Metric
R11, R27, R30, R31, R32, R71, R133, R134: 4.7k; R_0603_1608Metric
R12: 1.5k; R_0603_1608Metric
R13, R15, R16, R19: 10R; R_0603_1608Metric
R17, R22, R24, R26, R56, R57: 330R; R_0603_1608Metric
R18: 20k; R_0603_1608Metric
R20: 210k; R_0603_1608Metric
R21, R29: 100k; R_0603_1608Metric
R25: 40.2k; R_0603_1608Metric
R28: 24.9k; R_0603_1608Metric
R35, R36, R37: 33R; R_0603_1608Metric
R38: 68.1k; R_0603_1608Metric
R40: 12.1k 1%; R_0603_1608Metric
R45, R46: 680R; R_0603_1608Metric; JLCPCB C269704
R47, R79, R80, R81, R82, R83, R84, R97, R98, R99, R100, R101, R102, R115, R116, R117, R118, R119, R120, R127, R128, R129, R130, R131, R132, R141, R142, R143, R144, R145, R146, R164, R165, R166, R167, R168: 4.7k; R_0603_1608Metric; JLCPCB C237118
R54: 330R; R_0603_1608Metric; JLCPCB C101062
R55, R59, R60, R61, R62: 10k; R_0603_1608Metric; JLCPCB C269704
R58, R70: 20k; R_0603_1608Metric; JLCPCB C269704
R65: 120R; R_0603_1608Metric; JLCPCB C269704
R67: 4.7k; R_0603_1608Metric; JLCPCB C269704
R68: 20R_1%; R_2512_6332Metric
R72, R73, R74, R75, R76, R77, R78, R85, R86, R87, R88, R89, R90, R91, R92, R93, R94, R95, R96, R103, R104, R105, R106, R107, R108, R109, R110, R111, R112, R113, R114, R121, R122, R123, R124, R125, R126, R135, R136, R137, R138, R139, R140, R159, R160, R161, R162, R163: 10k; R_0603_1608Metric; JLCPCB C238881
RV1: 07D270K; RV_Disc_D7mm_W3.5mm_P5mm; JLCPCB C317745
SW1: SW_Push; SW_PUSH_6mm_H13mm
SW2: SUPLA_SWITCH; SW_Tactile_SPST_Angled_PTS645Vx39-2LFS
U1: MP1584EN_module; MP1584-_module
U2: AMS1117-3.3; SOT-223-3_TabPin2
U3: LAN8720A; QFN-24-1EP_4x4mm_P0.5mm_EP2.6x2.6mm
U4: MP1584EN; SOIC127P600X170-9N
U5: CH340G; SOIC-16_3.9x9.9mm_P1.27mm
U6: ESP32-WROOM-32D; ESP32-WROOM-32
U7: P82B96; SO-8_3.9x4.9mm_P1.27mm; JLCPCB C32103
U8: CD4053B; SOIC-16W_5.3x10.2mm_P1.27mm
U9: ISO7220A; SOIC-8_3.9x4.9mm_P1.27mm
U10: MAX485E; SOP-8_3.9x4.9mm_P1.27mm
U11: INA226; VSSOP-10_3x3mm_P0.5mm
U12, U13, U14, U15, U16, U17, U18, U19, U20, U21, U22, U23, U24, U25, U26, U27, U28, U29, U30, U31, U32, U33, U34, U35, U36, U37, U38, U39, U40, U41, U44, U45, U46, U47, U48, U49, U50, U51, U52, U53, U54: PC817X2NIP0F; SOT254P975X400-4N; JLCPCB C6649
U42, U43: MCP23017_SS; SSOP-28_5.3x10.2mm_P0.65mm
X1: 50MHz; Oscillator_SMD_EuroQuartz_XO91-4Pin_7.0x5.0mm_HandSoldering
Y1: CSTNE12_12MHz; Resonator_SMD_muRata_CSTxExxV-3Pin_3.0x1.1mm

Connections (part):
1_WIRE_OUT: J12.2, R71.1, U6.23 (IO15)
+3.3VLAN: C2.1, C3.1, C4.1, C24.1, J3.4, J3.5, L1.2, R5.2, R6.2, R7.2, R8.2, R11.1, R12.1, R13.1, R33.2, R34.2, U3.1 (VDD2A), U3.19 (VDD1A), X1.4 (Vcc)
+5P: C12.1, D3.1 (K), Q4.3 (D), U5.16 (VCC)
+5V: C14.1, C27.1, D2.1 (K), J1.2, J5.4, J12.1, Q4.2 (S), R10.1, R55.2, R63.2, R71.2, U2.3 (VI), U8.16 (VDD), U9.1 (VCC1)
+5VA: C30.1, J9.5, R63.1, U9.8 (VCC2)
+5V_USB: D3.2 (A), J4.1 (VBUS), R67.1
+24V: C18.1, J5.2, J6.1, J7.1, J8.1, J10.1, J11.1, JP1.2, Q13.2 (E), R21.2, R68.1, R103.1, R106.1, U1.3 (IN1+), U1.4 (IN2+), U4.7 (VIN), U11.8 (Vbus), U11.9 (Vin-), U27.3
+48V: J13.2, Q11.2 (E), R85.1, R94.1, R95.1, R105.1, U18.3
+A: D12.1 (A1), R58.2, R64.2, R65.2, U9.2 (INA), U10.6 (A)
+A_OUT: J9.6, R64.1, U9.7 (OUTA)
-B: D12.2 (A2), R65.1, R66.2, R70.1, U9.3 (INB), U10.7 (B)
-B_OUT: J9.7, R66.1, U9.6 (OUTB)
/RBIAS: R40.2, U3.24 (RBIAS)
/RXN: J3.6, R6.1, U3.22 (RXN)
/RXP: J3.3, R8.1, U3.23 (RXP)
/TXN: J3.2, R7.1, U3.20 (TXN)
/TXP: J3.1, R5.1, U3.21 (TXP)
CH_RX: J1.5, U5.3 (RXD), U8.2 (B0)
CH_TX: J1.6, U5.2 (TXD), U8.12 (A0)
CONTROL_RS485: R60.2, U6.8 (IO32), U10.2 (~RE), U10.3 (DE)
ESP_RX: R14.1, R18.2, U6.34 (RXD0/IO3)
ESP_RX_HV: R14.2, U8.14 (A)
ESP_SCL: I2C1.3, J5.8, R32.2, U6.29 (IO5), U7.7 (SCL), U11.5 (SCL), U42.12 (SCK), U43.12 (SCK)
ESP_SDA: I2C1.4, J5.7, R31.2, U6.26 (IO4), U7.1 (SDA), U11.4 (SDA), U42.13 (SDA), U43.13 (SDA)
ESP_TX: Q3.2 (S), R9.2, U6.35 (TXD0/IO1)
ESP_TX_HV: Q3.3 (D), R10.2, U8.15 (B)
ESP_UART2_RX: J12.8, U6.27 (IO16)
ESP_UART2_TX: J12.7, U6.28 (IO17)
ETH_CRS_DV: R19.1, U6.12 (IO27)
ETH_MDC: U3.13 (MDC), U6.37 (IO23)
ETH_MDIO: R12.2, U3.12 (MDIO), U6.30 (IO18)
ETH_RXD0: R15.1, U6.10 (IO25)
ETH_RXD1: R16.1, U6.11 (IO26)
ETH_TXD0: U3.17 (TXD0), U6.31 (IO19)
ETH_TXD1: U3.18 (TXD1), U6.36 (IO22)
ETH_TXEN: U3.16 (TXEN), U6.33 (IO21)
GND: C2.2, C3.2, C4.2, C5.2, C6.2, C7.2, C8.2, C10.2, C11.2, C12.2, C13.2, C14.2, C15.2, C21.2, C23.2, C24.2, C25.2, C26.2, C27.2, C28.2, C29.2, C31.2, C32.2, C33.2, C34.2, C35.2, C36.2, C37.2, C38.2, C39.2, C40.2, C41.2, C42.2, C43.2, C44.2, C45.2, C46.2, C47.2, C48.2, C49.2, C50.2, C51.2, C52.2, C53.2, C54.2, C55.2, C56.2, C57.2, C58.2, C59.2, C60.2, C61.2, C62.2, C63.2, C64.2, C65.2, C66.2, C67.2, C68.2, C69.2, C70.2, D4.1 (K), D8.3, D12.3 (common), I2C1.2, J1.1, J5.1, J5.3, J5.5, J9.4, J12.3, L2.2, L4.1, Q2.2 (E), Q9.2 (E), Q12.2 (E), R18.1, R40.1, R41.1, R42.1, R43.1, R44.1, R54.2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
GND1: J13.1, Q10.2 (E), U18.2, U19.2, U20.2, U20.3, U28.2
GNDA: C30.2, J9.8, Q10.3 (C), Q12.3 (C), R69.1, U9.5 (GND2), U12.2, U13.2, U14.2, U15.2, U16.2, U17.2, U21.2, U22.2, U23.2, U24.2, U25.2, U26.2, U30.2, U31.2, U32.2, U33.2, U34.2, U35.2, U36.2, U37.2, U38.2, U39.2, U40.2, U41.2, U44.2, U45.2, U46.2, U47.2, U48.2, U49.2, U50.2, U51.2, U52.2, U53.2, U54.2
GNDS: C16.2, C17.2, C18.2, C20.2, C22.2, D5.2 (A), D6.1 (K), J2.1, R25.2, R28.2, R29.2, R38.2, RV1.2, U1.1 (IN1-), U1.2 (IN2-), U4.5 (GND), U4.9 (GND)
GPIO0_ESP32: J1.3, Q6.3 (C), R30.2, R35.2, R36.1, SW2.2, U6.25 (IO0)
GPIO12_INPUT: C37.1, J12.6, R78.1, U6.14 (IO12)
GPIO13_INPUT: C44.1, J12.5, R93.1, U6.16 (IO13)
GPIO33_INPUT: C51.1, J12.4, R114.1, U6.9 (IO33)
GPIO34_ONLY_INPUT: C50.1, R113.1, U6.6 (IO34), U35.4
GPIO34_OUT: J11.4, R120.2
GPIO35_ONLY_INPUT: C59.1, R126.1, U6.7 (IO35), U41.4
GPIO35_OUT: J11.3, R132.2
GPIO36_ONLY_INPUT: C65.1, R140.1, U6.4 (SENSOR_VP), U49.4
GPIO36_OUT: J11.2, R146.2
MCP_1: C31.1, R72.1, U12.4, U42.1 (GPB0)
MCP_1_OUT: J6.2, R79.2
MCP_2: C38.1, R87.1, U21.4, U42.2 (GPB1)
MCP_2_OUT: J6.3, R97.2
MCP_3: C45.1, R108.1, U30.4, U42.3 (GPB2)
MCP_3_OUT: J6.4, R115.2
MCP_4: C54.1, R121.1, U36.4, U42.4 (GPB3)
MCP_4_OUT: J6.5, R127.2
MCP_5: C60.1, R135.1, U42.5 (GPB4), U44.4
MCP_5_OUT: J6.6, R141.2
MCP_6: C66.1, R159.1, U42.6 (GPB5), U50.4
MCP_6_OUT: J6.7, R164.2
MCP_7: C32.1, R73.1, U13.4, U42.7 (GPB6)
MCP_7_OUT: J6.8, R80.2
MCP_8: C39.1, R88.1, U22.4, U42.8 (GPB7)
MCP_8_OUT: J10.2, R98.2
MCP_9: C46.1, R109.1, U31.4, U43.1 (GPB0)
MCP_9_OUT: J10.3, R116.2
MCP_10: C55.1, R122.1, U37.4, U43.2 (GPB1)
MCP_10_OUT: J10.4, R128.2
MCP_11: C61.1, R136.1, U43.3 (GPB2), U45.4
MCP_11_OUT: J10.5, R142.2
MCP_12: C67.1, R160.1, U43.4 (GPB3), U51.4
MCP_12_OUT: J10.6, R165.2
MCP_13: C33.1, R74.1, U14.4, U43.5 (GPB4)
MCP_13_OUT: J10.7, R81.2
MCP_14: C40.1, R89.1, U23.4, U43.6 (GPB5)
MCP_14_OUT: J10.8, R99.2
MCP_15: C47.1, R110.1, U32.4, U43.7 (GPB6)
MCP_15_OUT: J7.2, R117.2
MCP_16: C56.1, R123.1, U38.4, U43.8 (GPB7)
MCP_16_OUT: J7.3, R129.2
MCP_17: C62.1, R137.1, U43.25 (GPA4), U46.4
MCP_17_OUT: J7.4, R143.2
MCP_18: C68.1, R161.1, U43.24 (GPA3), U52.4
MCP_18_OUT: J7.5, R166.2
MCP_19: C34.1, R75.1, U15.4, U43.23 (GPA2)
MCP_19_OUT: J7.6, R82.2
MCP_20: C41.1, R90.1, U24.4, U43.22 (GPA1)
MCP_20_OUT: J7.7, R100.2
MCP_21: C48.1, R111.1, U33.4, U43.21 (GPA0)
MCP_21_OUT: J7.8, R118.2
MCP_22: C57.1, R124.1, U39.4, U42.28 (GPA7)
MCP_22_OUT: J8.8, R130.2
MCP_23: C63.1, R138.1, U42.27 (GPA6), U47.4
MCP_23_OUT: J8.7, R144.2
MCP_24: C69.1, R162.1, U42.26 (GPA5), U53.4
MCP_24_OUT: J8.6, R167.2
MCP_25: C35.1, R76.1, U16.4, U42.25 (GPA4)
MCP_25_OUT: J8.5, R83.2
MCP_26: C42.1, R91.1, U25.4, U42.24 (GPA3)
MCP_26_OUT: J8.4, R101.2
MCP_27: C49.1, R112.1, U34.4, U42.23 (GPA2)
MCP_27_OUT: J8.3, R119.2
MCP_28: C58.1, R125.1, U40.4, U42.22 (GPA1)
MCP_28_OUT: J8.2, R131.2
MCP_29: C64.1, R139.1, U42.21 (GPA0), U48.4
MCP_29_OUT: J11.8, R145.2
MCP_30: C70.1, R163.1, U43.28 (GPA7), U54.4
MCP_30_OUT: J11.7, R168.2
MCP_31: C36.1, R77.1, U17.4, U43.27 (GPA6)
MCP_31_OUT: J11.6, R84.2
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

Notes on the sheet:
INA226
Switch_User
RS485
I2C
Pin_Down_PCB
OLED
MCP23017
Ethernet
ESP32
INPUTS
Input Board ESP v0.1
UART Multiplexer
Power Supply
Programing

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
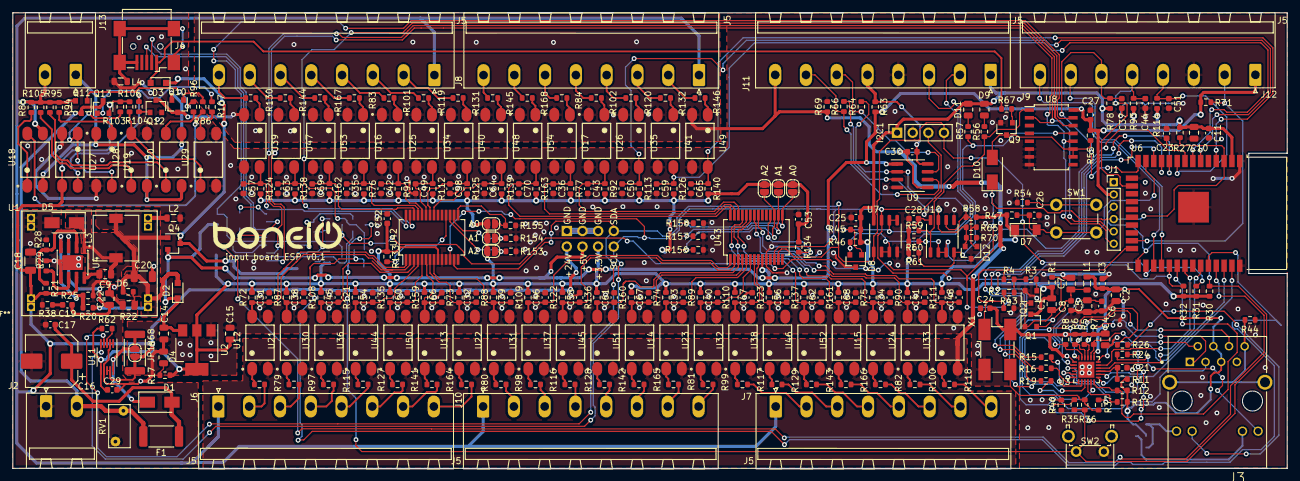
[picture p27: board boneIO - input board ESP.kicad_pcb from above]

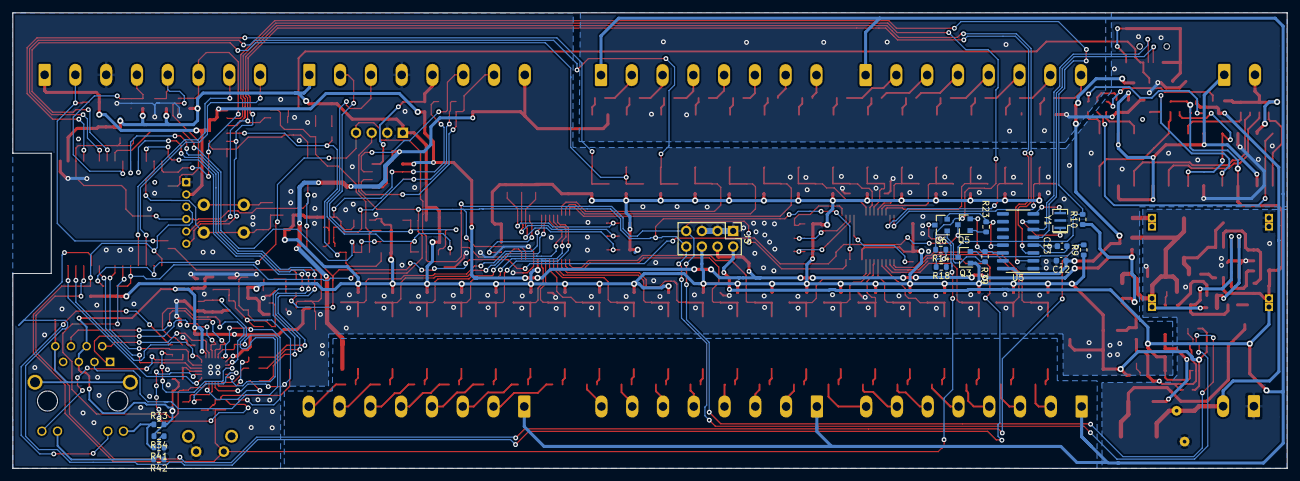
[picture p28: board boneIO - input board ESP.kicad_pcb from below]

Board: 2 copper layers, 207.0 x 74.0 mm, 334 parts (18 on the bottom side), 229 nets.

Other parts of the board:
A0, A0#2, A1, A1#2, A2, A2#2: NO; SolderJumper-2_P1.3mm_Open_RoundedPad1.0x1.5mm

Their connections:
unnamed 139: A2#2.2; also elsewhere on the board
unnamed 140: A1#2.2; also elsewhere on the board
unnamed 141: A0#2.2; also elsewhere on the board
unnamed 142: A2.2; also elsewhere on the board
unnamed 143: A1.2; also elsewhere on the board
unnamed 144: A0.2; also elsewhere on the board

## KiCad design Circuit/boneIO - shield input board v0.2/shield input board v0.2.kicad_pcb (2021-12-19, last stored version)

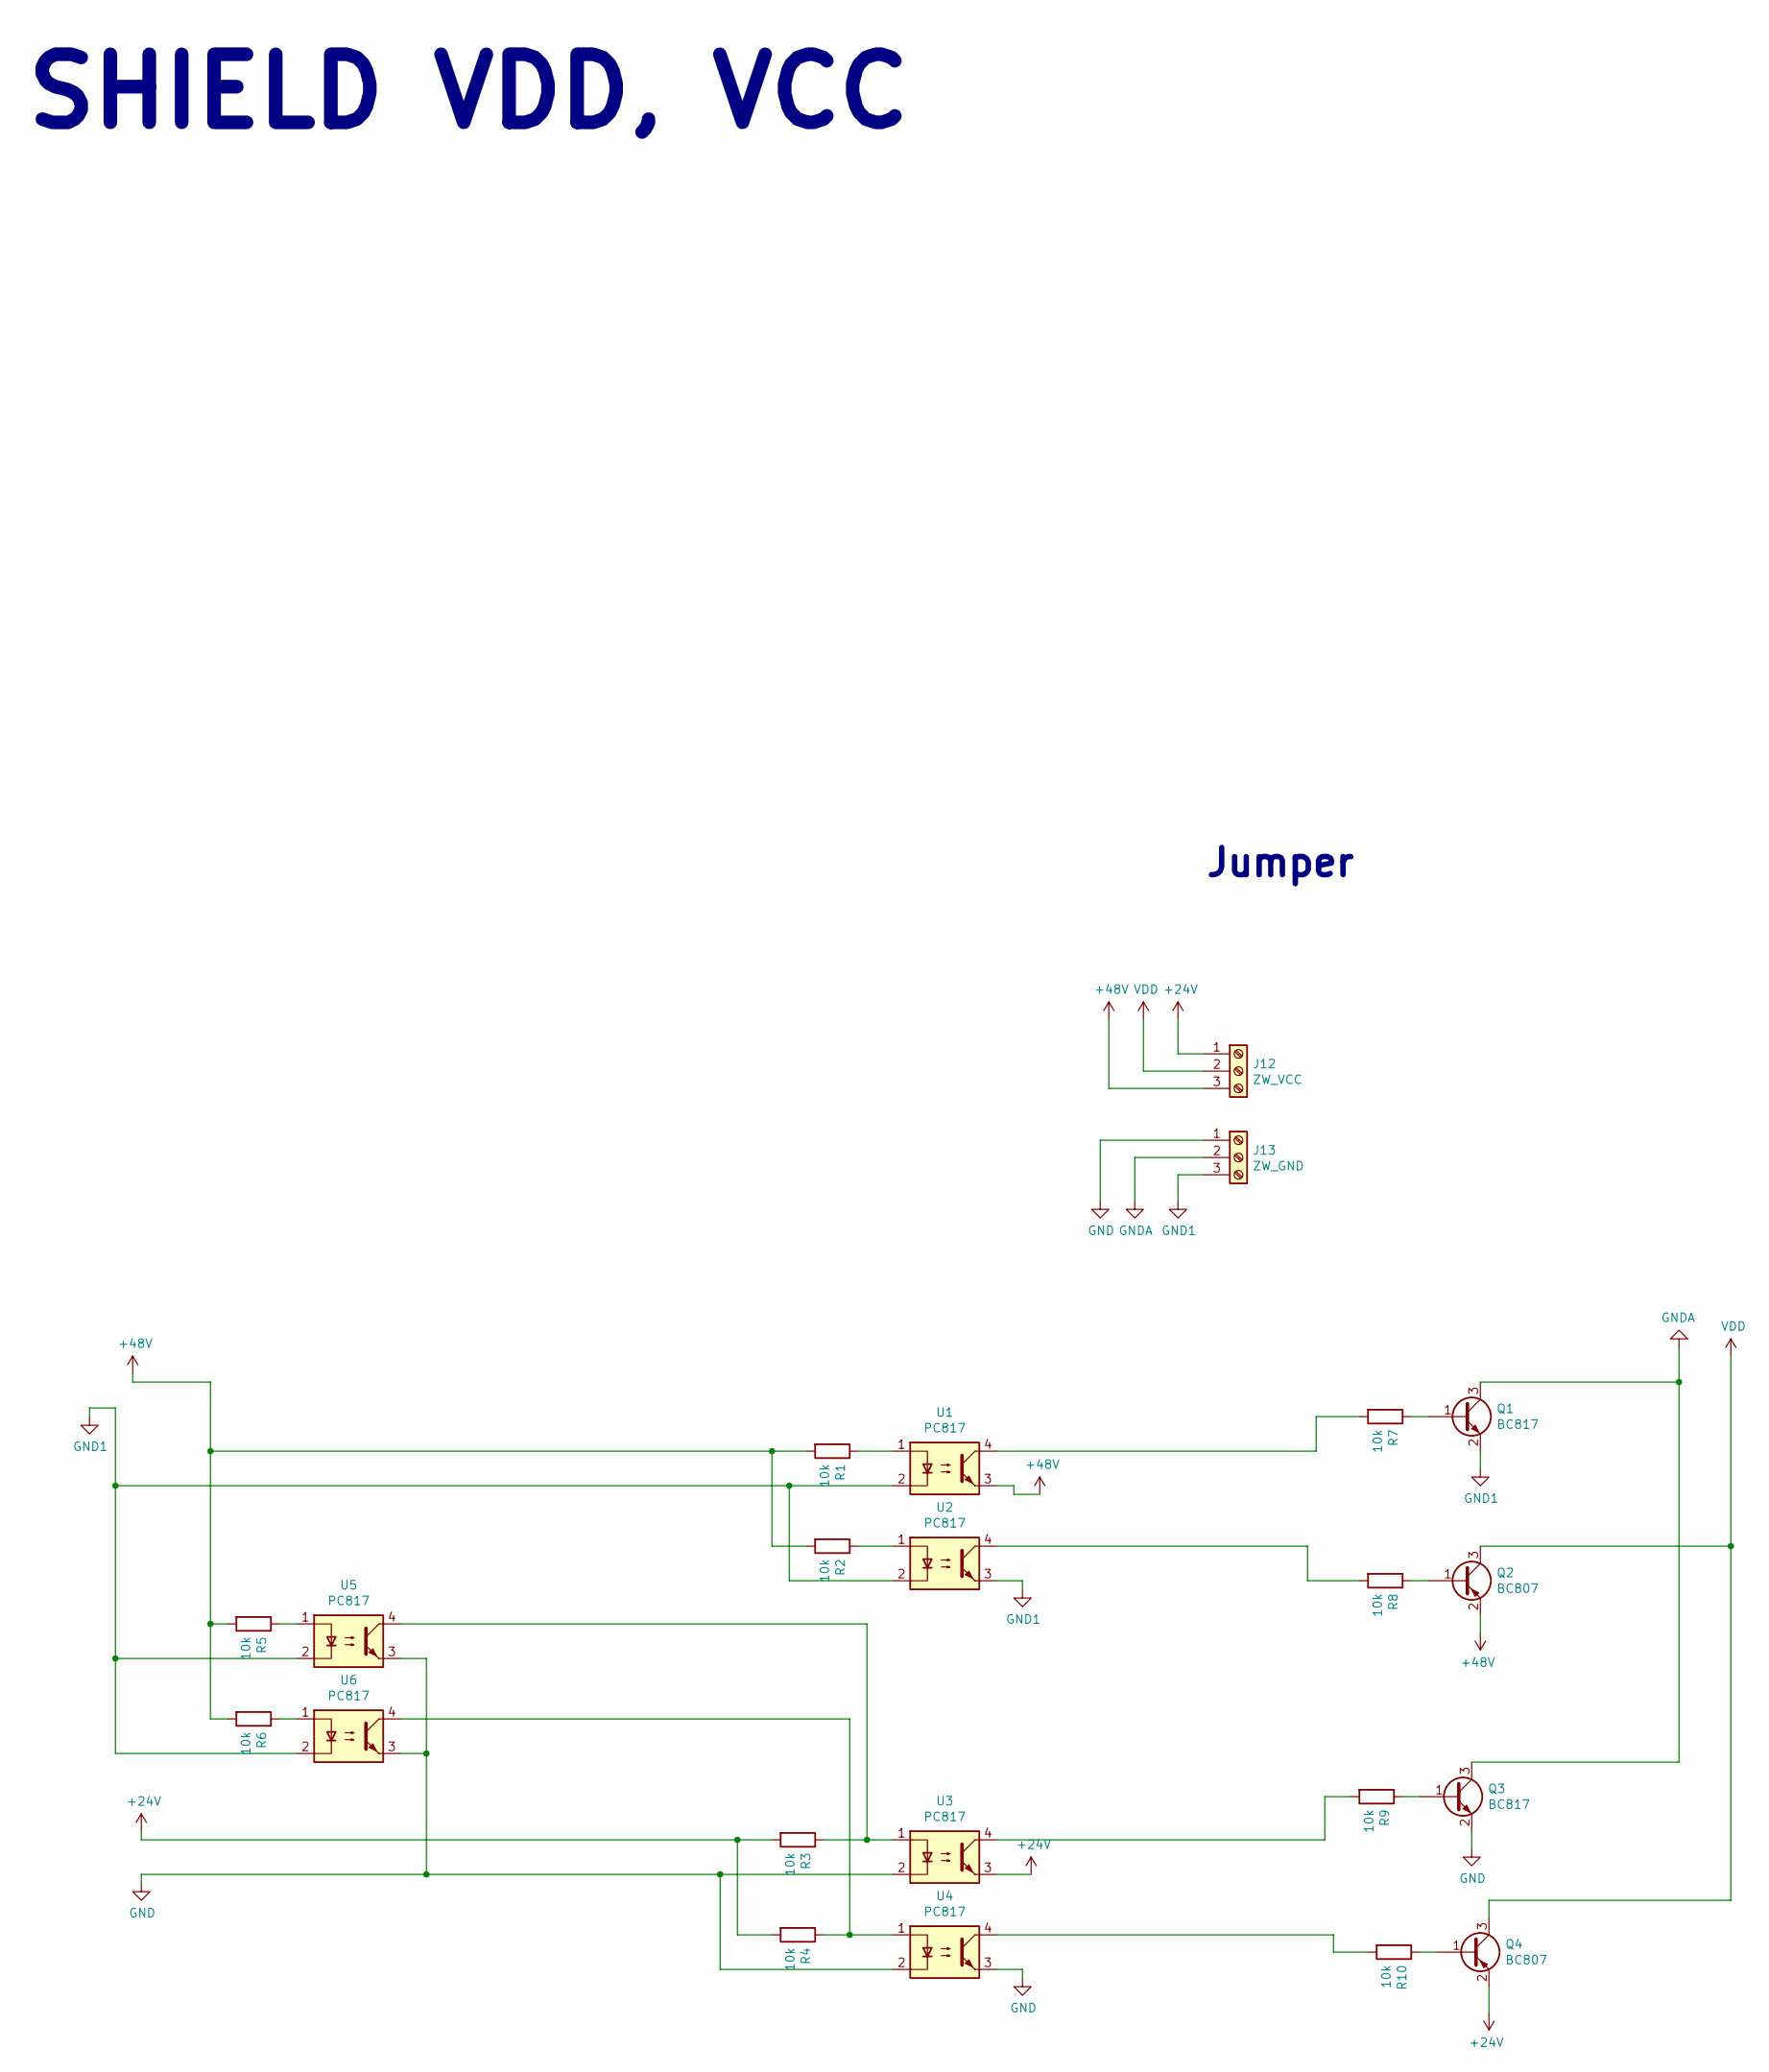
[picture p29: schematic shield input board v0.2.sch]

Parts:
J12: ZW_VCC; PinHeader_1x03_P2.54mm_Vertical
J13: ZW_GND; PinHeader_1x03_P2.54mm_Vertical
Q1, Q3: BC817; SOT-23
Q2, Q4: BC807; SOT-23
R1, R2, R3, R4, R5, R6, R7, R8, R9, R10: 10k; R_0603_1608Metric; JLCPCB C237118
U1, U2, U3, U4, U5, U6: PC817; DIP-4_W7.62mm; JLCPCB C6649

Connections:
+24V: J12.1, Q4.2 (E), R3.2, R4.2, U3.3
+48V: J12.3, Q2.2 (E), R1.2, R2.2, R5.2, R6.2, U1.3
GND: J13.1, Q3.2 (E), U3.2, U4.2, U4.3, U5.3, U6.3
GND1: J13.3, Q1.2 (E), U1.2, U2.2, U2.3, U5.2, U6.2
GNDA: J13.2, Q1.3 (C), Q3.3 (C)
unnamed: Q1.1 (B), R7.1
unnamed: Q2.1 (B), R8.1
unnamed: Q3.1 (B), R9.1
unnamed: Q4.1 (B), R10.1
unnamed: R1.1, U1.1
unnamed: R2.1, U2.1
unnamed: R3.1, U3.1, U5.4
unnamed: R4.1, U4.1, U6.4
unnamed: R5.1, U5.1
unnamed: R6.1, U6.1
unnamed: R7.2, U1.4
unnamed: R8.2, U2.4
unnamed: R9.2, U3.4
unnamed: R10.2, U4.4
VDD: J12.2, Q2.3 (C), Q4.3 (C)

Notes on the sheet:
Jumper
SHIELD VDD, VCC

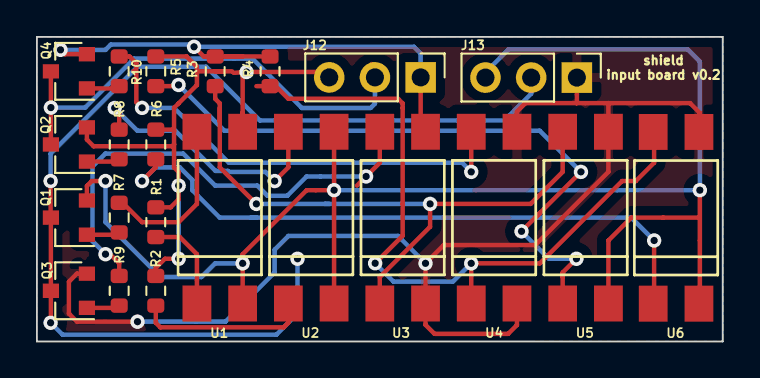
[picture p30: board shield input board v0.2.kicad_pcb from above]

Board: 2 copper layers, 38.1 x 16.9 mm, 22 parts (0 on the bottom side), 20 nets.

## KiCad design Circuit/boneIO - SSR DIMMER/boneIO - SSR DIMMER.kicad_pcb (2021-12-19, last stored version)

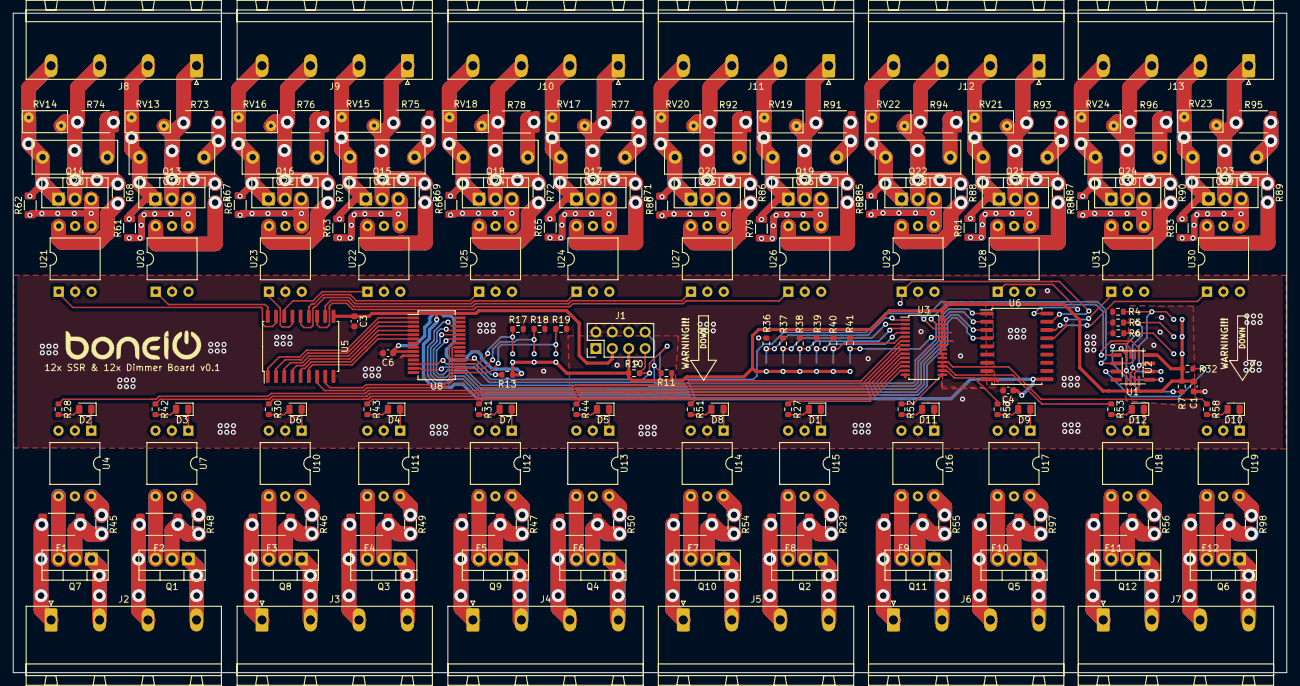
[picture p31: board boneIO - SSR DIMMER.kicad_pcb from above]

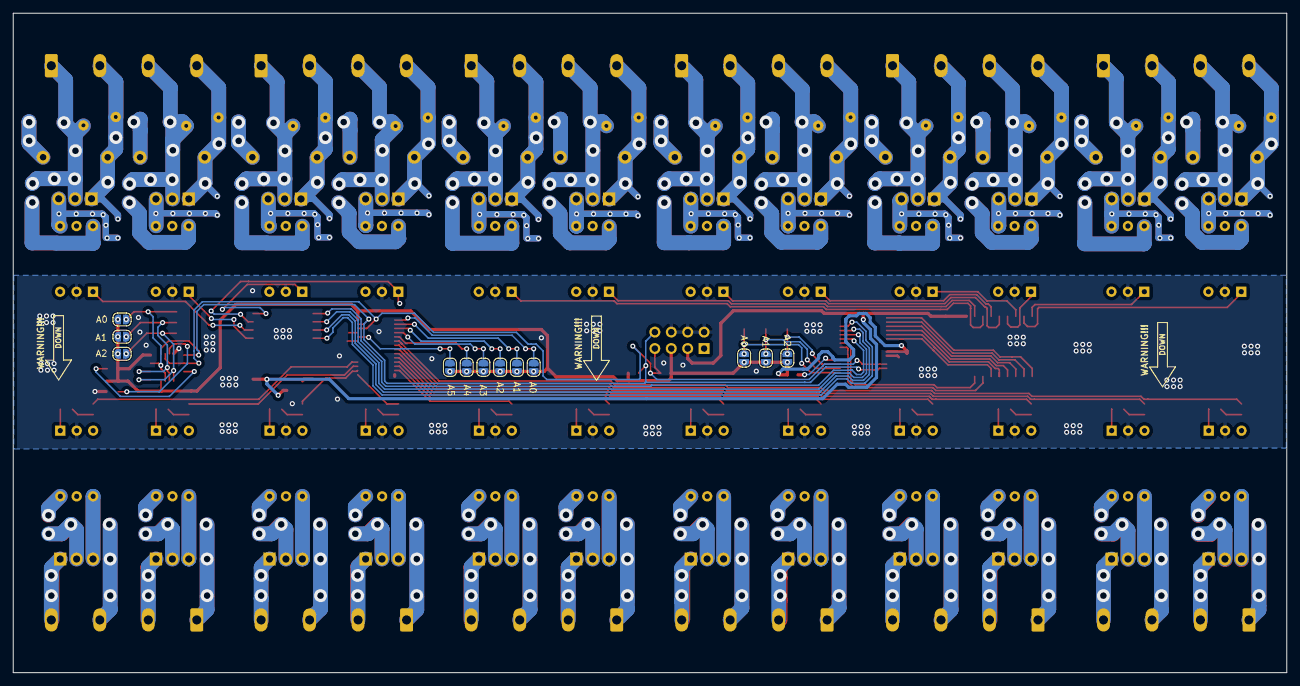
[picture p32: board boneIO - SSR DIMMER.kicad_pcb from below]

Board: 2 copper layers, 197.0 x 102.0 mm, 208 parts (12 on the bottom side), 200 nets.

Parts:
A0, A0#2, A0#3, A1, A1#2, A1#3, A2, A2#2, A2#3, A3, A4, A5: Jumper_NO_Small; SolderJumper-2_P1.3mm_Open_RoundedPad1.0x1.5mm
C1, C3, C4, C6: 100n; C_0603_1608Metric
C19, C20, C21, C22, C23, C24, C25, C26, C27, C28, C29, C30: MKP-X2-10NR10/275V; C_Rect_L13.0mm_W5.0mm_P10.00mm_FKS3_FKP3_MKS4
D1, D2, D3, D4, D5, D6, D7, D8, D9, D10, D11, D12: LED_ALT; LED_0805_2012Metric
F1, F2, F3, F4, F5, F6, F7, F8, F9, F10, F11, F12: 4A; Fuse_2512_6332Metric
J1: Conn_02x04_Odd_Even; PinHeader_2x04_P2.54mm_Vertical
J2, J3, J4, J5, J6, J7: DIMMER; PhoenixContact_GMSTBA_2,5_4-G_1x04_P7.50mm_Horizontal
J8, J9, J10, J11, J12, J13: Screw_Terminal_01x04; PhoenixContact_GMSTBA_2,5_4-G_1x04_P7.50mm_Horizontal
Q1, Q2, Q3, Q4, Q5, Q6, Q7, Q8, Q9, Q10, Q11, Q12: BT136-600; TO-220-3_Vertical
Q13, Q14, Q15, Q16, Q17, Q18, Q19, Q20, Q21, Q22, Q23, Q24: BTA12-600B; TO-220-3_Vertical
R4, R5, R6, R17, R18, R19, R36, R37, R38, R39, R40, R41: 10k; R_0603_1608Metric
R7, R10, R11, R13, R32: 4.7k; R_0603_1608Metric
R27, R28, R30, R31, R42, R43, R44, R51, R52, R53, R57, R58: 220R; R_0603_1608Metric
R29, R45, R46, R47, R48, R49, R50, R54, R55, R56, R97, R98: 1k; R_1206_3216Metric
R61, R62, R63, R64, R65, R66, R79, R80, R81, R82, R83, R84: 330R; R_1206_3216Metric
R67, R68, R69, R70, R71, R72, R85, R86, R87, R88, R89, R90: 360R; R_1206_3216Metric
R73, R74, R75, R76, R77, R78, R91, R92, R93, R94, R95, R96: 39R/2W; R_2512_6332Metric
RV13, RV14, RV15, RV16, RV17, RV18, RV19, RV20, RV21, RV22, RV23, RV24: JVR07N431K; RV_Disc_D7mm_W3.4mm_P5mm
U1: MCP9808-E_SO8; SO-8_3.9x4.9mm_P1.27mm
U2: MCP9808-E_MS; MSOP-8_3x3mm_P0.65mm
U3: PCA9685PW; TSSOP-28_4.4x9.7mm_P0.65mm
U4, U7, U10, U11, U12, U13, U14, U15, U16, U17, U18, U19, U20, U21, U22, U23, U24, U25, U26, U27, U28, U29, U30, U31: MOC3041M; DIP-6_W10.16mm
U5, U6: ULN2803A; SOIC-18W_7.5x11.6mm_P1.27mm
U8: MCP23017_SS; SSOP-28_5.3x10.2mm_P0.65mm

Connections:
+3V3: A0.1, A0#2.2, A0#3.1, A1.1, A1#2.2, A1#3.1, A2.1, A2#2.2, A2#3.1, A3.1, A4.1, A5.1, C1.1, C6.1, J1.5, R7.1, R10.1, R11.1, R13.1, R32.1, U1.8, U2.8, U3.28, U8.9
+5V: C3.1, C4.1, J1.3, U5.10, U6.10
GND: C1.2, C3.2, C4.2, C6.2, J1.2, J1.4, J1.6, R4.2, R5.2, R6.2, R17.2, R18.2, R19.2, R36.2, R37.2, R38.2, R39.2, R40.2, R41.2, U1.4, U2.4, U3.14, U3.23, U3.25, U4.2, U5.9, U6.9, U7.2, U8.10, U10.2, U11.2, U12.2, U13.2, U14.2, U15.2, U16.2, U17.2, U18.2, U19.2, U20.2, U21.2, U22.2, U23.2, U24.2, U25.2, U26.2, U27.2, U28.2, U29.2, U30.2, U31.2
K1: U5.1, U8.1
K2: U5.2, U8.2
K3: U5.3, U8.3
K4: U5.4, U8.4
K5: U5.5, U8.5
K6: U5.6, U8.6
K7: U5.7, U8.21
K8: U5.8, U8.22
K9: U6.1, U8.23
K10: U6.2, U8.24
K11: U6.3, U8.25
K12: U6.4, U8.26
unnamed: C19.1, R73.2
unnamed: C19.2, J8.2, Q13.1, R61.2, RV13.2
unnamed: C20.1, R74.2
unnamed: C20.2, J8.4, Q14.1, R62.2, RV14.2
unnamed: C21.1, R75.2
unnamed: C21.2, J9.2, Q15.1, R63.2, RV15.2
unnamed: C22.1, R76.2
unnamed: C22.2, J9.4, Q16.1, R64.2, RV16.2
unnamed: C23.1, R77.2
unnamed: C23.2, J10.2, Q17.1, R65.2, RV17.2
unnamed: C24.1, R78.2
unnamed: C24.2, J10.4, Q18.1, R66.2, RV18.2
unnamed: C25.1, R91.2
unnamed: C25.2, J11.2, Q19.1, R79.2, RV19.2
unnamed: C26.1, R92.2
unnamed: C26.2, J11.4, Q20.1, R80.2, RV20.2
unnamed: C27.1, R93.2
unnamed: C27.2, J12.2, Q21.1, R81.2, RV21.2
unnamed: C28.1, R94.2
unnamed: C28.2, J12.4, Q22.1, R82.2, RV22.2
unnamed: C29.1, R95.2
unnamed: C29.2, J13.2, Q23.1, R83.2, RV23.2
unnamed: C30.1, R96.2
unnamed: C30.2, J13.4, Q24.1, R84.2, RV24.2
unnamed: D1.1, U15.1
unnamed: D1.2, R27.2
unnamed: D2.1, U4.1
unnamed: D2.2, R28.2
unnamed: D3.1, U7.1
unnamed: D3.2, R42.2
unnamed: D4.1, U11.1
unnamed: D4.2, R43.2
unnamed: D5.1, U13.1
unnamed: D5.2, R44.2
unnamed: D6.1, U10.1
unnamed: D6.2, R30.2
unnamed: D7.1, U12.1
unnamed: D7.2, R31.2
unnamed: D8.1, U14.1
unnamed: D8.2, R51.2
unnamed: D9.1, U17.1
unnamed: D9.2, R57.2
unnamed: D10.1, U19.1
unnamed: D10.2, R58.2
unnamed: D11.1, U16.1
unnamed: D11.2, R52.2
unnamed: D12.1, U18.1
unnamed: D12.2, R53.2
unnamed: F1.1, Q7.2, R45.2
unnamed: F1.2, J2.1
unnamed: F2.1, Q1.2, R48.2
unnamed: F2.2, J2.3
unnamed: F3.1, Q8.2, R46.2
unnamed: F3.2, J3.1
unnamed: F4.1, Q3.2, R49.2
unnamed: F4.2, J3.3
unnamed: F5.1, Q9.2, R47.2
unnamed: F5.2, J4.1
unnamed: F6.1, Q4.2, R50.2
unnamed: F6.2, J4.3
unnamed: F7.1, Q10.2, R54.2
unnamed: F7.2, J5.1
unnamed: F8.1, Q2.2, R29.2
unnamed: F8.2, J5.3
unnamed: F9.1, Q11.2, R55.2
unnamed: F9.2, J6.1
unnamed: F10.1, Q5.2, R97.2
unnamed: F10.2, J6.3
unnamed: F11.1, Q12.2, R56.2
unnamed: F11.2, J7.1
unnamed: F12.1, Q6.2, R98.2
unnamed: F12.2, J7.3
unnamed: J2.2, Q7.1
unnamed: J2.4, Q1.1
unnamed: J3.2, Q8.1
unnamed: J3.4, Q3.1
unnamed: J4.2, Q9.1
unnamed: J4.4, Q4.1
unnamed: J5.2, Q10.1
unnamed: J5.4, Q2.1
unnamed: J6.2, Q11.1
unnamed: J6.4, Q5.1
unnamed: J7.2, Q12.1
unnamed: J7.4, Q6.1
unnamed: J8.1, Q13.2, R67.1, R73.1, RV13.1
unnamed: J8.3, Q14.2, R68.1, R74.1, RV14.1
unnamed: J9.1, Q15.2, R69.1, R75.1, RV15.1
unnamed: J9.3, Q16.2, R70.1, R76.1, RV16.1
unnamed: J10.1, Q17.2, R71.1, R77.1, RV17.1
unnamed: J10.3, Q18.2, R72.1, R78.1, RV18.1
unnamed: J11.1, Q19.2, R85.1, R91.1, RV19.1
unnamed: J11.3, Q20.2, R86.1, R92.1, RV20.1
unnamed: J12.1, Q21.2, R87.1, R93.1, RV21.1
unnamed: J12.3, Q22.2, R88.1, R94.1, RV22.1
unnamed: J13.1, Q23.2, R89.1, R95.1, RV23.1
unnamed: J13.3, Q24.2, R90.1, R96.1, RV24.1
unnamed: A0#3.2, R4.1, U1.7, U2.7
unnamed: A1#3.2, R5.1, U1.6, U2.6
unnamed: A2#3.2, R6.1, U1.5, U2.5
unnamed: A2#2.1, R17.1, U8.17
unnamed: A1#2.1, R18.1, U8.16
unnamed: A0#2.1, R19.1, U8.15
unnamed: A0.2, R36.1, U3.1
unnamed: A1.2, R37.1, U3.2
unnamed: A2.2, R38.1, U3.3
unnamed: A3.2, R39.1, U3.4
unnamed: A4.2, R40.1, U3.5
unnamed: A5.2, R41.1, U3.24
unnamed: Q1.3, U7.4
unnamed: Q2.3, U15.4
unnamed: Q3.3, U11.4
unnamed: Q4.3, U13.4
unnamed: Q5.3, U17.4
unnamed: Q6.3, U19.4
unnamed: Q7.3, U4.4
unnamed: Q8.3, U10.4
unnamed: Q9.3, U12.4
unnamed: Q10.3, U14.4
unnamed: Q11.3, U16.4
unnamed: Q12.3, U18.4
unnamed: Q13.3, R61.1, U20.4
unnamed: Q14.3, R62.1, U21.4
unnamed: Q15.3, R63.1, U22.4
unnamed: Q16.3, R64.1, U23.4
unnamed: Q17.3, R65.1, U24.4
unnamed: Q18.3, R66.1, U25.4
unnamed: Q19.3, R79.1, U26.4
unnamed: Q20.3, R80.1, U27.4
unnamed: Q21.3, R81.1, U28.4
unnamed: Q22.3, R82.1, U29.4
unnamed: Q23.3, R83.1, U30.4
unnamed: Q24.3, R84.1, U31.4
unnamed: R7.2, U2.3
unnamed: R13.2, U8.18
unnamed: R29.1, U15.6
unnamed: R32.2, U1.3
unnamed: R45.1, U4.6
unnamed: R46.1, U10.6
unnamed: R47.1, U12.6
unnamed: R48.1, U7.6
unnamed: R49.1, U11.6
unnamed: R50.1, U13.6
unnamed: R54.1, U14.6
unnamed: R55.1, U16.6
unnamed: R56.1, U18.6
unnamed: R67.2, U20.6
unnamed: R68.2, U21.6
unnamed: R69.2, U22.6
unnamed: R70.2, U23.6
unnamed: R71.2, U24.6
unnamed: R72.2, U25.6
unnamed: R85.2, U26.6
unnamed: R86.2, U27.6
unnamed: R87.2, U28.6
unnamed: R88.2, U29.6
unnamed: R89.2, U30.6
unnamed: R90.2, U31.6
unnamed: R97.1, U17.6
unnamed: R98.1, U19.6
PWM1: R28.1, U3.6
PWM2: R42.1, U3.7
PWM3: R30.1, U3.8
PWM4: R43.1, U3.9
PWM5: R31.1, U3.10
PWM6: R44.1, U3.11
PWM7: R51.1, U3.12
PWM8: R27.1, U3.13
PWM9: R52.1, U3.15
PWM10: R57.1, U3.16
PWM11: R53.1, U3.17
PWM12: R58.1, U3.18
RELAY1: U5.18, U20.1
RELAY2: U5.17, U21.1
RELAY3: U5.16, U22.1
RELAY4: U5.15, U23.1
RELAY5: U5.14, U24.1
RELAY6: U5.13, U25.1
RELAY7: U5.12, U26.1
RELAY8: U5.11, U27.1
RELAY9: U6.18, U28.1
RELAY10: U6.17, U29.1
RELAY11: U6.16, U30.1
RELAY12: U6.15, U31.1
SCL: J1.7, R10.2, U1.2, U2.2, U3.26, U8.12
SDA: J1.8, R11.2, U1.1, U2.1, U3.27, U8.13

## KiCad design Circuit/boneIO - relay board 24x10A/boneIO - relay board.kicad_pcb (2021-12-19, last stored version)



Board: 2 copper layers, 197.0 x 102.0 mm, 75 parts (10 on the bottom side), 116 nets.

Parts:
A0, A0#2, A0#3, A1, A1#2, A1#3, A2, A2#2, A2#3: NO_Small; SolderJumper-2_P1.3mm_Open_RoundedPad1.0x1.5mm
C1, C2, C3, C4, C5, C6: 100n; C_0603_1608Metric
J1, J2, J4, J5, J6, J7, J8, J9, J10, J11, J12, J13: Screw_Terminal_01x04; PhoenixContact_GMSTBA_2,5_4-G_1x04_P7.50mm_Horizontal
J3: Conn_02x04_Odd_Even; PinHeader_2x04_P2.54mm_Vertical
JP4: SolderJumper_3_Bridged12; SolderJumper-3_P1.3mm_Bridged12_RoundedPad1.0x1.5mm
K1, K2, K3, K4, K5, K6, K7, K8, K9, K10, K11, K12, K13, K14, K15, K16, K17, K18, K19, K20, K21, K22, K23, K24: SANYOU_SRD_Form_C; Relay_SPDT_SANYOU_SRD_Series_Form_C
R1, R2, R3, R9, R10, R11, R13, R14, R15: 10k; R_0603_1608Metric
R4, R5, R6, R7, R8, R12: 4.7k; R_0603_1608Metric
U1: MCP9808-E_SO8; SO-8_3.9x4.9mm_P1.27mm
U2: MCP9808-E_MS; SOP65P490X110-8N
U3, U4, U5: ULN2803A; SOIC-18W_7.5x11.6mm_P1.27mm
U6, U7: MCP23017_SS; SSOP-28_5.3x10.2mm_P0.65mm

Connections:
+3V3: A0.1, A0#2.1, A0#3.1, A1.1, A1#2.1, A1#3.1, A2.1, A2#2.1, A2#3.1, C1.1, C5.1, C6.1, J3.5, R4.1, R5.1, R6.1, R7.1, R8.1, R12.1, U1.8, U2.8, U6.9, U7.9
+5V: J3.3, JP4.3
+24V: J3.1, JP4.1
GND: C1.2, C2.2, C3.2, C4.2, C5.2, C6.2, J3.2, J3.4, J3.6, R1.2, R2.2, R3.2, R9.2, R10.2, R11.2, R13.2, R14.2, R15.2, U1.4, U2.4, U3.9, U4.9, U5.9, U6.10, U7.10
K1: U3.1, U6.1
K2: U3.2, U6.2
K3: U3.3, U6.3
K4: U3.4, U6.4
K5: U3.5, U6.5
K6: U3.6, U6.6
K7: U5.4, U7.4
K8: U5.3, U7.3
K9: U5.2, U7.2
K10: U5.1, U7.1
K11: U4.8, U6.23
K12: U4.7, U6.24
K13: U4.6, U6.25
K14: U4.5, U6.26
K15: U4.4, U6.27
K16: U4.3, U6.28
K17: U5.8, U7.8
K18: U5.7, U7.7
K19: U5.6, U7.6
K20: U5.5, U7.5
K21: U3.7, U7.21
K22: U3.8, U7.22
K23: U4.1, U6.21
K24: U4.2, U6.22
unnamed: J1.1, K1.3
unnamed: J1.2, K1.1
unnamed: J1.3, K2.3
unnamed: J1.4, K2.1
unnamed: J2.1, K3.3
unnamed: J2.2, K3.1
unnamed: J2.3, K4.3
unnamed: J2.4, K4.1
unnamed: J4.1, K5.3
unnamed: J4.2, K5.1
unnamed: J4.3, K6.3
unnamed: J4.4, K6.1
unnamed: J5.1, K7.3
unnamed: J5.2, K7.1
unnamed: J5.3, K8.3
unnamed: J5.4, K8.1
unnamed: J6.1, K9.3
unnamed: J6.2, K9.1
unnamed: J6.3, K10.3
unnamed: J6.4, K10.1
unnamed: J7.1, K12.3
unnamed: J7.2, K12.1
unnamed: J7.3, K11.3
unnamed: J7.4, K11.1
unnamed: J8.1, K13.3
unnamed: J8.2, K13.1
unnamed: J8.3, K14.3
unnamed: J8.4, K14.1
unnamed: J9.1, K15.3
unnamed: J9.2, K15.1
unnamed: J9.3, K16.3
unnamed: J9.4, K16.1
unnamed: J10.1, K18.3
unnamed: J10.2, K18.1
unnamed: J10.3, K17.3
unnamed: J10.4, K17.1
unnamed: J11.1, K20.3
unnamed: J11.2, K20.1
unnamed: J11.3, K19.3
unnamed: J11.4, K19.1
unnamed: J12.1, K21.3
unnamed: J12.2, K21.1
unnamed: J12.3, K22.3
unnamed: J12.4, K22.1
unnamed: J13.1, K23.3
unnamed: J13.2, K23.1
unnamed: J13.3, K24.3
unnamed: J13.4, K24.1
unnamed: A0#3.2, R1.1, U1.7, U2.7
unnamed: A1#3.2, R2.1, U1.6, U2.6
unnamed: A2#3.2, R3.1, U1.5, U2.5
unnamed: A2#2.2, R9.1, U6.17
unnamed: A1#2.2, R10.1, U6.16
unnamed: A0#2.2, R11.1, U6.15
unnamed: A2.2, R13.1, U7.17
unnamed: A1.2, R14.1, U7.16
unnamed: A0.2, R15.1, U7.15
unnamed: R4.2, U1.3
unnamed: R5.2, U2.3
unnamed: R8.2, U6.18
unnamed: R12.2, U7.18
RELAY1: K1.5, U4.11
RELAY2: K2.5, U4.12
RELAY3: K3.5, U4.13
RELAY4: K4.5, U4.14
RELAY5: K5.5, U4.15
RELAY6: K6.5, U4.16
RELAY7: K7.5, U4.17
RELAY8: K8.5, U4.18
RELAY9: K9.5, U5.18
RELAY10: K10.5, U5.17
RELAY11: K11.5, U3.18
RELAY12: K12.5, U3.17
RELAY13: K16.5, U3.16
RELAY14: K15.5, U3.15
RELAY15: K14.5, U3.14
RELAY16: K13.5, U3.13
RELAY17: K17.5, U3.12
RELAY18: K18.5, U3.11
RELAY19: K19.5, U5.14
RELAY20: K20.5, U5.13
RELAY21: K21.5, U5.11
RELAY22: K22.5, U5.12
RELAY23: K23.5, U5.16
RELAY24: K24.5, U5.15
SCL: J3.7, R6.2, U1.2, U2.2, U6.12, U7.12
SDA: J3.8, R7.2, U1.1, U2.1, U6.13, U7.13
VCC: C2.1, C3.1, C4.1, JP4.2, K1.2, K2.2, K3.2, K4.2, K5.2, K6.2, K7.2, K8.2, K9.2, K10.2, K11.2, K12.2, K13.2, K14.2, K15.2, K16.2, K17.2, K18.2, K19.2, K20.2, K21.2, K22.2, K23.2, K24.2, U3.10, U4.10, U5.10

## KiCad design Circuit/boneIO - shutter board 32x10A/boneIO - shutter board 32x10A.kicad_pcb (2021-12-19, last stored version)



Board: 2 copper layers, 197.0 x 102.0 mm, 89 parts (9 on the bottom side), 148 nets.

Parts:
A0, A0#2, A0#3, A1, A1#2, A1#3, A2, A2#2, A2#3: NO_Small; SolderJumper-2_P1.3mm_Open_RoundedPad1.0x1.5mm
C1, C2, C3, C4, C5, C6: 100nF; C_0603_1608Metric
C7: 100n; C_0603_1608Metric
J1, J2, J3, J4, J5, J6, J7, J8, J9, J10, J11, J12, J13, J14, J16, J17: Screw_Terminal_01x03; PhoenixContact_GMSTBA_2,5_3-G_1x03_P7.50mm_Horizontal
J15: Conn_02x04_Odd_Even; PinHeader_2x04_P2.54mm_Vertical
JP7: SolderJumper_3_Open; SolderJumper-3_P1.3mm_Bridged12_RoundedPad1.0x1.5mm
R1, R2, R3, R8, R9, R10, R13, R14, R15: 10k; R_0603_1608Metric
R4, R7, R11, R12, R16, R17: 4.7k; R_0603_1608Metric
Relay1, Relay2, Relay3, Relay4, Relay5, Relay6, Relay7, Relay8, Relay9, Relay10, Relay11, Relay12, Relay13, Relay14, Relay15, Relay16, Relay17, Relay18, Relay19, Relay20, Relay21, Relay22, Relay23, Relay24, Relay25, Relay26, Relay27, Relay28, Relay29, Relay30, Relay31, Relay32: FINDER-36.11; Relay_SPDT_Finder_36.11
U1, U2: MCP23017_SS; SSOP-28_5.3x10.2mm_P0.65mm
U3, U4, U5, U6: ULN2803A; SOIC-18W_7.5x11.6mm_P1.27mm
U7: MCP9808_SO8; SO-8_3.9x4.9mm_P1.27mm
U8: MCP9808_MSOP; MSOP-8_3x3mm_P0.65mm

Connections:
+3V3: A0.1, A0#2.1, A0#3.1, A1.1, A1#2.1, A1#3.1, A2.1, A2#2.1, A2#3.1, C1.2, C4.2, C7.1, J15.5, R4.2, R7.2, R11.2, R12.2, R16.1, R17.1, U1.9, U2.9, U7.8, U8.8
+5V: J15.3, JP7.3
+24V: J15.1, JP7.1
GND: C1.1, C2.1, C3.1, C4.1, C5.1, C6.1, C7.2, J15.2, J15.4, J15.6, R1.2, R2.2, R3.2, R8.2, R9.2, R10.2, R13.2, R14.2, R15.2, U1.10, U2.10, U3.9, U4.9, U5.9, U6.9, U7.4, U8.4
unnamed: J1.1, Relay1.11
unnamed: J1.2, Relay1.14
unnamed: J1.3, Relay2.14
unnamed: J2.1, Relay3.11
unnamed: J2.2, Relay3.14
unnamed: J2.3, Relay4.14
unnamed: J3.1, Relay5.11
unnamed: J3.2, Relay5.14
unnamed: J3.3, Relay6.14
unnamed: J4.1, Relay7.11
unnamed: J4.2, Relay7.14
unnamed: J4.3, Relay8.14
unnamed: J5.1, Relay9.11
unnamed: J5.2, Relay9.14
unnamed: J5.3, Relay10.14
unnamed: J6.1, Relay11.11
unnamed: J6.2, Relay11.14
unnamed: J6.3, Relay12.14
unnamed: J7.1, Relay13.11
unnamed: J7.2, Relay13.14
unnamed: J7.3, Relay14.14
unnamed: J8.1, Relay15.11
unnamed: J8.2, Relay15.14
unnamed: J8.3, Relay16.14
unnamed: J9.1, Relay18.14
unnamed: J9.2, Relay17.14
unnamed: J9.3, Relay17.11
unnamed: J10.1, Relay20.14
unnamed: J10.2, Relay19.14
unnamed: J10.3, Relay19.11
unnamed: J11.1, Relay22.14
unnamed: J11.2, Relay21.14
unnamed: J11.3, Relay21.11
unnamed: J12.1, Relay24.14
unnamed: J12.2, Relay23.14
unnamed: J12.3, Relay23.11
unnamed: J13.1, Relay26.14
unnamed: J13.2, Relay25.14
unnamed: J13.3, Relay25.11
unnamed: J14.1, Relay28.14
unnamed: J14.2, Relay27.14
unnamed: J14.3, Relay27.11
unnamed: J16.1, Relay32.14
unnamed: J16.2, Relay31.14
unnamed: J16.3, Relay31.11
unnamed: J17.1, Relay30.14
unnamed: J17.2, Relay29.14
unnamed: J17.3, Relay29.11
unnamed: A2#3.2, R1.1, U1.17
unnamed: A1.2, R2.1, U1.16
unnamed: A0#3.2, R3.1, U1.15
unnamed: A2#2.2, R8.1, U2.17
unnamed: A1#3.2, R9.1, U2.16
unnamed: A0#2.2, R10.1, U2.15
unnamed: A0.2, R13.1, U7.7, U8.7
unnamed: A1#2.2, R14.1, U7.6, U8.6
unnamed: A2.2, R15.1, U7.5, U8.5
unnamed: R4.1, U1.18
unnamed: R7.1, U2.18
unnamed: R16.2, U7.3
unnamed: R17.2, U8.3
unnamed: Relay1.12, Relay2.11
unnamed: Relay3.12, Relay4.11
unnamed: Relay5.12, Relay6.11
unnamed: Relay7.12, Relay8.11
unnamed: Relay9.12, Relay10.11
unnamed: Relay11.12, Relay12.11
unnamed: Relay13.12, Relay14.11
unnamed: Relay15.12, Relay16.11
unnamed: Relay17.12, Relay18.11
unnamed: Relay19.12, Relay20.11
unnamed: Relay21.12, Relay22.11
unnamed: Relay23.12, Relay24.11
unnamed: Relay25.12, Relay26.11
unnamed: Relay27.12, Relay28.11
unnamed: Relay29.12, Relay30.11
unnamed: Relay31.12, Relay32.11
unnamed: U1.1, U3.1
unnamed: U1.2, U3.2
unnamed: U1.3, U3.3
unnamed: U1.4, U3.4
unnamed: U1.5, U3.5
unnamed: U1.6, U3.6
unnamed: U1.7, U3.7
unnamed: U1.8, U3.8
unnamed: U1.21, U4.1
unnamed: U1.22, U4.2
unnamed: U1.23, U4.3
unnamed: U1.24, U4.4
unnamed: U1.25, U4.5
unnamed: U1.26, U4.6
unnamed: U1.27, U4.7
unnamed: U1.28, U4.8
unnamed: U2.1, U5.1
unnamed: U2.2, U5.2
unnamed: U2.3, U5.3
unnamed: U2.4, U5.4
unnamed: U2.5, U5.5
unnamed: U2.6, U5.6
unnamed: U2.7, U5.7
unnamed: U2.8, U5.8
unnamed: U2.21, U6.1
unnamed: U2.22, U6.2
unnamed: U2.23, U6.3
unnamed: U2.24, U6.4
unnamed: U2.25, U6.5
unnamed: U2.26, U6.6
unnamed: U2.27, U6.7
unnamed: U2.28, U6.8
RELAY1: Relay1.A1, U4.18
RELAY2: Relay2.A1, U4.17
RELAY3: Relay3.A1, U4.16
RELAY4: Relay4.A1, U4.15
RELAY5: Relay5.A1, U4.14
RELAY6: Relay6.A1, U4.13
RELAY7: Relay7.A1, U4.12
RELAY8: Relay8.A1, U4.11
RELAY9: Relay9.A1, U3.18
RELAY10: Relay10.A1, U3.17
RELAY11: Relay11.A1, U3.16
RELAY12: Relay12.A1, U3.15
RELAY13: Relay13.A1, U3.14
RELAY14: Relay14.A1, U3.13
RELAY15: Relay15.A1, U3.12
RELAY16: Relay16.A1, U3.11
RELAY17: Relay17.A1, U6.18
RELAY18: Relay18.A1, U6.17
RELAY19: Relay19.A1, U6.16
RELAY20: Relay20.A1, U6.15
RELAY21: Relay21.A1, U6.14
RELAY22: Relay22.A1, U6.13
RELAY23: Relay23.A1, U6.12
RELAY24: Relay24.A1, U6.11
RELAY25: Relay25.A1, U5.18
RELAY26: Relay26.A1, U5.17
RELAY27: Relay27.A1, U5.16
RELAY28: Relay28.A1, U5.15
RELAY29: Relay29.A1, U5.14
RELAY30: Relay30.A1, U5.13
RELAY31: Relay31.A1, U5.12
RELAY32: Relay32.A1, U5.11
SCL: J15.7, R11.1, U1.12, U2.12, U7.2, U8.2
SDA: J15.8, R12.1, U1.13, U2.13, U7.1, U8.1
VCC: C2.2, C3.2, C5.2, C6.2, JP7.2, Relay1.A2, Relay2.A2, Relay3.A2, Relay4.A2, Relay5.A2, Relay6.A2, Relay7.A2, Relay8.A2, Relay9.A2, Relay10.A2, Relay11.A2, Relay12.A2, Relay13.A2, Relay14.A2, Relay15.A2, Relay16.A2, Relay17.A2, Relay18.A2, Relay19.A2, Relay20.A2, Relay21.A2, Relay22.A2, Relay23.A2, Relay24.A2, Relay25.A2, Relay26.A2, Relay27.A2, Relay28.A2, Relay29.A2, Relay30.A2, Relay31.A2, Relay32.A2, U3.10, U4.10, U5.10, U6.10

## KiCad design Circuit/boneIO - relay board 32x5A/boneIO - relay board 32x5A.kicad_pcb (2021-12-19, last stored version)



Board: 2 copper layers, 197.0 x 102.0 mm, 89 parts (10 on the bottom side), 132 nets.

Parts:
A0, A0#2, A0#3, A1, A1#2, A1#3, A2, A2#2, A2#3: NO_Small; SolderJumper-2_P1.3mm_Open_RoundedPad1.0x1.5mm
C1, C2, C3, C4, C5, C6: 100nF; C_0603_1608Metric
C7: 100n; C_0603_1608Metric
J1, J2, J3, J4, J5, J6, J7, J8, J9, J10, J11, J13, J14, J15, J16, J17: Screw_Terminal_01x03; PhoenixContact_GMSTBA_2,5_3-G_1x03_P7.50mm_Horizontal
J12: Conn_02x04_Odd_Even; PinHeader_2x04_P2.54mm_Vertical
JP7: SolderJumper_3_Open; SolderJumper-3_P1.3mm_Bridged12_RoundedPad1.0x1.5mm
K1, K2, K3, K4, K5, K6, K7, K8, K9, K10, K11, K12, K13, K14, K15, K16, K17, K18, K19, K20, K21, K22, K23, K24, K25, K26, K27, K28, K29, K30, K31, K32: HF46F
R1, R3, R4, R5, R7, R8, R11, R12, R13: 10k; R_0603_1608Metric
R2, R6, R9, R10, R14, R15: 4.7k; R_0603_1608Metric
U1, U4: MCP23017_SS; SSOP-28_5.3x10.2mm_P0.65mm
U2, U3, U5, U6: ULN2803A; SOIC-18W_7.5x11.6mm_P1.27mm
U7: MCP9808_SO8; SO-8_3.9x4.9mm_P1.27mm
U8: MCP9808_MSOP; MSOP-8_3x3mm_P0.65mm

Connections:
+3V3: A0.1, A0#2.1, A0#3.1, A1.1, A1#2.1, A1#3.1, A2.1, A2#2.1, A2#3.1, C1.2, C4.2, C7.1, J12.5, R2.2, R6.2, R9.2, R10.2, R14.1, R15.1, U1.9, U4.9, U7.8, U8.8
+5V: J12.3, JP7.3
+24V: J12.1, JP7.1
GND: C1.1, C2.1, C3.1, C4.1, C5.1, C6.1, C7.2, J12.2, J12.4, J12.6, R1.2, R3.2, R4.2, R5.2, R7.2, R8.2, R11.2, R12.2, R13.2, U1.10, U2.9, U3.9, U4.10, U5.9, U6.9, U7.4, U8.4
unnamed: J1.1, K1.3, K2.3
unnamed: J1.2, K1.4
unnamed: J1.3, K2.4
unnamed: J2.1, K3.3, K4.3
unnamed: J2.2, K3.4
unnamed: J2.3, K4.4
unnamed: J3.1, K5.3, K6.3
unnamed: J3.2, K5.4
unnamed: J3.3, K6.4
unnamed: J4.1, K7.3, K8.3
unnamed: J4.2, K7.4
unnamed: J4.3, K8.4
unnamed: J5.1, K9.3, K10.3
unnamed: J5.2, K9.4
unnamed: J5.3, K10.4
unnamed: J6.1, K11.3, K12.3
unnamed: J6.2, K11.4
unnamed: J6.3, K12.4
unnamed: J7.1, K13.3, K14.3
unnamed: J7.2, K13.4
unnamed: J7.3, K14.4
unnamed: J8.1, K15.3, K16.3
unnamed: J8.2, K15.4
unnamed: J8.3, K16.4
unnamed: J9.1, K17.3, K18.3
unnamed: J9.2, K18.4
unnamed: J9.3, K17.4
unnamed: J10.1, K19.3, K20.3
unnamed: J10.2, K20.4
unnamed: J10.3, K19.4
unnamed: J11.1, K21.3, K22.3
unnamed: J11.2, K22.4
unnamed: J11.3, K21.4
unnamed: J13.1, K23.3, K24.3
unnamed: J13.2, K24.4
unnamed: J13.3, K23.4
unnamed: J14.1, K25.3, K26.3
unnamed: J14.2, K26.4
unnamed: J14.3, K25.4
unnamed: J15.1, K27.3, K28.3
unnamed: J15.2, K28.4
unnamed: J15.3, K27.4
unnamed: J16.1, K29.3, K30.3
unnamed: J16.2, K30.4
unnamed: J16.3, K29.4
unnamed: J17.1, K31.3, K32.3
unnamed: J17.2, K32.4
unnamed: J17.3, K31.4
unnamed: A2#3.2, R1.1, U1.17
unnamed: A1#3.2, R3.1, U1.16
unnamed: A0#3.2, R4.1, U1.15
unnamed: A2#2.2, R5.1, U4.17
unnamed: A1#2.2, R7.1, U4.16
unnamed: A0#2.2, R8.1, U4.15
unnamed: A0.2, R11.1, U7.7, U8.7
unnamed: A1.2, R12.1, U7.6, U8.6
unnamed: A2.2, R13.1, U7.5, U8.5
unnamed: R2.1, U1.18
unnamed: R6.1, U4.18
unnamed: R14.2, U7.3
unnamed: R15.2, U8.3
unnamed: U1.1, U2.1
unnamed: U1.2, U2.2
unnamed: U1.3, U2.3
unnamed: U1.4, U2.4
unnamed: U1.5, U2.5
unnamed: U1.6, U2.6
unnamed: U1.7, U2.7
unnamed: U1.8, U2.8
unnamed: U1.21, U3.1
unnamed: U1.22, U3.2
unnamed: U1.23, U3.3
unnamed: U1.24, U3.4
unnamed: U1.25, U3.5
unnamed: U1.26, U3.6
unnamed: U1.27, U3.7
unnamed: U1.28, U3.8
unnamed: U4.1, U5.1
unnamed: U4.2, U5.2
unnamed: U4.3, U5.3
unnamed: U4.4, U5.4
unnamed: U4.5, U5.5
unnamed: U4.6, U5.6
unnamed: U4.7, U5.7
unnamed: U4.8, U5.8
unnamed: U4.21, U6.1
unnamed: U4.22, U6.2
unnamed: U4.23, U6.3
unnamed: U4.24, U6.4
unnamed: U4.25, U6.5
unnamed: U4.26, U6.6
unnamed: U4.27, U6.7
unnamed: U4.28, U6.8
RELAY1: K1.2, U2.11
RELAY2: K2.2, U2.12
RELAY3: K3.2, U2.13
RELAY4: K4.2, U2.14
RELAY5: K5.2, U2.15
RELAY6: K6.2, U2.16
RELAY7: K7.2, U2.17
RELAY8: K8.2, U2.18
RELAY9: K9.2, U5.11
RELAY10: K10.2, U5.12
RELAY11: K11.2, U5.13
RELAY12: K12.2, U5.14
RELAY13: K13.2, U5.15
RELAY14: K14.2, U5.16
RELAY15: K15.2, U5.17
RELAY16: K16.2, U5.18
RELAY17: K17.2, U3.18
RELAY18: K18.2, U3.17
RELAY19: K19.2, U3.16
RELAY20: K20.2, U3.15
RELAY21: K21.2, U3.14
RELAY22: K22.2, U3.13
RELAY23: K23.2, U3.12
RELAY24: K24.2, U3.11
RELAY25: K25.2, U6.18
RELAY26: K26.2, U6.17
RELAY27: K27.2, U6.16
RELAY28: K28.2, U6.15
RELAY29: K29.2, U6.14
RELAY30: K30.2, U6.13
RELAY31: K31.2, U6.12
RELAY32: K32.2, U6.11
SCL: J12.7, R9.1, U1.12, U4.12, U7.2, U8.2
SDA: J12.8, R10.1, U1.13, U4.13, U7.1, U8.1
VCC: C2.2, C3.2, C5.2, C6.2, JP7.2, K1.1, K2.1, K3.1, K4.1, K5.1, K6.1, K7.1, K8.1, K9.1, K10.1, K11.1, K12.1, K13.1, K14.1, K15.1, K16.1, K17.1, K18.1, K19.1, K20.1, K21.1, K22.1, K23.1, K24.1, K25.1, K26.1, K27.1, K28.1, K29.1, K30.1, K31.1, K32.1, U2.10, U3.10, U5.10, U6.10

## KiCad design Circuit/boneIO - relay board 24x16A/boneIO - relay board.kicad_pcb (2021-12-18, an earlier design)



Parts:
C1, C2, C3, C4, C5, C6: 100n; C_0603_1608Metric
J1, J2, J4, J5, J6, J7, J8, J9, J10, J11, J12, J13: Screw_Terminal_01x04; PhoenixContact_GMSTBA_2,5_4-G_1x04_P7.50mm_Horizontal
J3: Conn_02x04_Odd_Even; PinHeader_2x04_P2.54mm_Vertical
JP1, JP2, JP3, JP5, JP6, JP7, JP8, JP9, JP10: NO_Small; SolderJumper-2_P1.3mm_Open_RoundedPad1.0x1.5mm
JP4: SolderJumper_3_Bridged12; SolderJumper-3_P1.3mm_Bridged12_RoundedPad1.0x1.5mm
K1, K2, K3, K4, K5, K6, K7, K8, K9, K10, K11, K12, K13, K14, K15, K16, K17, K18, K19, K20, K21, K22, K23, K24: RM85-2011-35-1024; RM852011351024
R1, R2, R3, R9, R10, R11, R13, R14, R15: 10k; R_0603_1608Metric
R4, R5, R6, R7, R8, R12: 4.7k; R_0603_1608Metric
U1: MCP9808-E_SO8; SO-8_3.9x4.9mm_P1.27mm
U2: MCP9808-E_MS; SOP65P490X110-8N
U3, U4, U5: ULN2803A; SOIC-18W_7.5x11.6mm_P1.27mm
U6, U7: MCP23017_SS; SSOP-28_5.3x10.2mm_P0.65mm

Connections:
+5V: J3.3, JP4.3 (B)
+24V: J3.1, JP4.1 (A)
GND: C1.2, C2.2, C3.2, C4.2, C5.2, C6.2, J3.2, J3.4, J3.6, R1.2, R2.2, R3.2, R9.2, R10.2, R11.2, R13.2, R14.2, R15.2, U1.4 (GND), U2.4 (GND), U3.9 (GND), U4.9 (GND), U5.9 (GND), U6.10 (VSS), U7.10 (VSS)
K1: U3.1 (I1), U6.1 (GPB0)
K2: U3.2 (I2), U6.2 (GPB1)
K3: U3.3 (I3), U6.3 (GPB2)
K4: U3.4 (I4), U6.4 (GPB3)
K5: U3.5 (I5), U6.5 (GPB4)
K6: U3.6 (I6), U6.6 (GPB5)
K7: U5.4 (I4), U7.4 (GPB3)
K8: U5.3 (I3), U7.3 (GPB2)
K9: U5.2 (I2), U7.2 (GPB1)
K10: U5.1 (I1), U7.1 (GPB0)
K11: U4.8 (I8), U6.23 (GPA2)
K12: U4.7 (I7), U6.24 (GPA3)
K13: U4.6 (I6), U6.25 (GPA4)
K14: U4.5 (I5), U6.26 (GPA5)
K15: U4.4 (I4), U6.27 (GPA6)
K16: U4.3 (I3), U6.28 (GPA7)
K17: U5.8 (I8), U7.8 (GPB7)
K18: U5.7 (I7), U7.7 (GPB6)
K19: U5.6 (I6), U7.6 (GPB5)
K20: U5.5 (I5), U7.5 (GPB4)
K21: U3.7 (I7), U7.21 (GPA0)
K22: U3.8 (I8), U7.22 (GPA1)
K23: U4.1 (I1), U6.21 (GPA0)
K24: U4.2 (I2), U6.22 (GPA1)
unnamed: J1.1, K1.11, K1.21
unnamed: J1.2, K1.14, K1.24
unnamed: J1.3, K2.11, K2.21
unnamed: J1.4, K2.14, K2.24
unnamed: J2.1, K3.11, K3.21
unnamed: J2.2, K3.14, K3.24
unnamed: J2.3, K4.11, K4.21
unnamed: J2.4, K4.14, K4.24
unnamed: J4.1, K5.11, K5.21
unnamed: J4.2, K5.14, K5.24
unnamed: J4.3, K6.11, K6.21
unnamed: J4.4, K6.14, K6.24
unnamed: J5.1, K7.11, K7.21
unnamed: J5.2, K7.14, K7.24
unnamed: J5.3, K8.11, K8.21
unnamed: J5.4, K8.14, K8.24
unnamed: J6.1, K9.11, K9.21
unnamed: J6.2, K9.14, K9.24
unnamed: J6.3, K10.11, K10.21
unnamed: J6.4, K10.14, K10.24
unnamed: J7.1, K12.11, K12.21
unnamed: J7.2, K12.14, K12.24
unnamed: J7.3, K11.11, K11.21
unnamed: J7.4, K11.14, K11.24
unnamed: J8.1, K13.11, K13.21
unnamed: J8.2, K13.14, K13.24
unnamed: J8.3, K14.11, K14.21
unnamed: J8.4, K14.14, K14.24
unnamed: J9.1, K15.11, K15.21
unnamed: J9.2, K15.14, K15.24
unnamed: J9.3, K16.11, K16.21
unnamed: J9.4, K16.14, K16.24
unnamed: J10.1, K18.11, K18.21
unnamed: J10.2, K18.14, K18.24
unnamed: J10.3, K17.11, K17.21
unnamed: J10.4, K17.14, K17.24
unnamed: J11.1, K20.11, K20.21
unnamed: J11.2, K20.14, K20.24
unnamed: J11.3, K19.11, K19.21
unnamed: J11.4, K19.14, K19.24
unnamed: J12.1, K21.11, K21.21
unnamed: J12.2, K21.14, K21.24
unnamed: J12.3, K22.11, K22.21
unnamed: J12.4, K22.14, K22.24
unnamed: J13.1, K23.11, K23.21
unnamed: J13.2, K23.14, K23.24
unnamed: J13.3, K24.11, K24.21
unnamed: J13.4, K24.14, K24.24
unnamed: JP1.2, R1.1, U1.7 (A0), U2.7 (A0)
unnamed: JP2.2, R2.1, U1.6 (A1), U2.6 (A1)
unnamed: JP3.2, R3.1, U1.5 (A2), U2.5 (A2)
unnamed 78: JP5.2, R9.1, U6.17 (A2); also elsewhere on the board
unnamed 79: JP6.2, R10.1, U6.16 (A1); also elsewhere on the board
unnamed 80: JP7.2, R11.1, U6.15 (A0); also elsewhere on the board
unnamed 81: JP8.2, R13.1, U7.17 (A2); also elsewhere on the board
unnamed 82: JP9.2, R14.1, U7.16 (A1); also elsewhere on the board
unnamed 83: JP10.2, R15.1, U7.15 (A0); also elsewhere on the board
unnamed: R4.2, U1.3 (Alert)
unnamed: R5.2, U2.3 (Alert)
unnamed: R8.2, U6.18 (~RESET~)
unnamed: R12.2, U7.18 (~RESET~)
RELAY1: K1.A1, U4.15 (O4)
RELAY2: K2.A1, U4.14 (O5)
RELAY3: K3.A1, U4.13 (O6)
RELAY4: K4.A1, U4.12 (O7)
RELAY5: K5.A1, U4.11 (O8)
RELAY6: K6.A1, U4.18 (O1)
RELAY7: K7.A1, U4.17 (O2)
RELAY8: K8.A1, U4.16 (O3)
RELAY9: K9.A1, U5.18 (O1)
RELAY10: K10.A1, U5.17 (O2)
RELAY11: K11.A1, U3.17 (O2)
RELAY12: K12.A1, U3.18 (O1)
RELAY13: K16.A1, U3.11 (O8)
RELAY14: K15.A1, U3.12 (O7)
RELAY15: K14.A1, U3.13 (O6)
RELAY16: K13.A1, U3.14 (O5)
RELAY17: K17.A1, U3.15 (O4)
RELAY18: K18.A1, U3.16 (O3)
RELAY19: K19.A1, U5.12 (O7)
RELAY20: K20.A1, U5.11 (O8)
RELAY21: K21.A1, U5.14 (O5)
RELAY22: K22.A1, U5.13 (O6)
RELAY23: K23.A1, U5.15 (O4)
RELAY24: K24.A1, U5.16 (O3)
SCL: J3.7, R6.2, U1.2 (SCL), U2.2 (SCL), U6.12 (SCK), U7.12 (SCK)
SDA: J3.8, R7.2, U1.1 (SDA), U2.1 (SDA), U6.13 (SDA), U7.13 (SDA)
VCC: C2.1, C3.1, C4.1, JP4.2 (C), K1.A2, K2.A2, K3.A2, K4.A2, K5.A2, K6.A2, K7.A2, K8.A2, K9.A2, K10.A2, K11.A2, K12.A2, K13.A2, K14.A2, K15.A2, K16.A2, K17.A2, K18.A2, K19.A2, K20.A2, K21.A2, K22.A2, K23.A2, K24.A2, U3.10 (COM), U4.10 (COM), U5.10 (COM)

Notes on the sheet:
PINOUT
ULN2803A
RELAY
MCP9808
MCP23017
- relay board 24x16A v0.3
ADDRESS 0x22
ADDRESS 0x23
ADDRESS 0x48

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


Board: 2 copper layers, 197.0 x 102.0 mm, 75 parts (10 on the bottom side), 116 nets.

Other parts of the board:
A0, A0#2, A1, A1#2, A2, A2#2: NO_Small; SolderJumper-2_P1.3mm_Open_RoundedPad1.0x1.5mm

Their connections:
unnamed 78: A2#2.2; also elsewhere on the board
unnamed 79: A1#2.2; also elsewhere on the board
unnamed 80: A0#2.2; also elsewhere on the board
unnamed 81: A2.2; also elsewhere on the board
unnamed 82: A1.2; also elsewhere on the board
unnamed 83: A0.2; also elsewhere on the board

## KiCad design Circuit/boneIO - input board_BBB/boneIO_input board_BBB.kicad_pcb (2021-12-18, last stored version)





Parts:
BT1: Battery; Battery_Panasonic_CR1220-VCN_Vertical_CircularHoles
C1, C4, C9, C10, C11, C12, C13, C14, C15, C16, C17, C18, C19, C20, C21, C22, C23, C24, C25, C26, C27, C28, C29, C30, C31, C32, C33, C34, C35, C36, C37, C38, C39, C40, C41, C42, C43, C44, C45, C46, C47, C48, C49, C50, C51, C52, C53, C54, C55, C56, C57, C58, C59, C60, C61, C62: 100n; C_0603_1608Metric; JLCPCB C14663
C2: 100uF/50V; CP_Elec_8x10; JLCPCB C72480
C3: 100n_NC; C_0603_1608Metric; JLCPCB C14663
C5: 3n3; C_0805_2012Metric; JLCPCB C107149
C6, C7: 100uF/16V; CP_Elec_6.3x5.4; JLCPCB C72480
C8: 220u/35V; CP_Elec_8x10; JLCPCB C311611
D1: 1N4148; D_MiniMELF; JLCPCB C68883
D2: SS34; D_SMA; JLCPCB C64982
D3: SS34; D_SMA; JLCPCB C8678
D4: LED_RED_NC; LED_0805_2012Metric; JLCPCB C84256
D5: LED_RED; LED_0805_2012Metric; JLCPCB C84256
D6: 5V6; D_MiniMELF
D7: BAT54A; SOT-23
F1: Fuse_3A; Fuse_2512_6332Metric; JLCPCB C136367
F2: 500mA; Fuse_1206_3216Metric
J1: EXT_PSU; PhoenixContact_MSTBA_2,5_2-G_1x02_P5.00mm_Horizontal
J2, J5, J6, J7, J8, J9, J12, J13, J14: Screw_Terminal_01x08; 8pin
J3, J4: BeagleBone_Black_Header; PinHeader_2x23_P2.54mm_Vertical
J10: Conn_02x04_Odd_Even; PinSocket_2x04_P2.54mm_Vertical
J11: Screw_Terminal_01x04; Phoenix_1x04_P5.00mm_Horizontal
J15, J16: Screw_Terminal_01x02; Phoenix_1x02_P5.00mm_Horizontal
J17: OLED; PinSocket_1x04_P2.54mm_Vertical
JP1: 5V; SolderJumper-2_P1.3mm_Open_Pad1.0x1.5mm
L1: BLM21PG221SN1D; L_0805_2012Metric; JLCPCB C85840
L2: 4.7uH; L_12x12mm_H6mm; JLCPCB C338848
Q1, Q4: BC817; SOT-23
Q2, Q6: BSS138; SOT-23
Q3, Q5: BC807; SOT-23
R1: 0k_NC; R_0805_2012Metric; JLCPCB C238881
R2, R3, R4, R6, R7, R24, R25, R26: 4.7k; R_0603_1608Metric; JLCPCB C238881
R5, R34, R35, R36, R37, R38, R39, R40, R48, R49, R50, R51, R52, R53, R54, R62, R63, R64, R65, R66, R67, R68, R71, R72, R78, R81, R82, R83, R84, R85, R86, R90, R94, R95, R96, R97, R98, R102, R105, R106, R108, R109, R110, R116, R117, R118, R120, R121, R122, R126, R129, R131, R132, R133, R134: 4.7k; R_0603_1608Metric; JLCPCB C237118
R8, R9, R10, R11, R12, R13, R18, R19, R20, R21, R22, R27, R28, R29, R30, R31, R32, R41, R42, R43, R44, R45, R46, R55, R56, R57, R58, R59, R60, R61, R73, R74, R75, R76, R77, R79, R80, R87, R88, R89, R91, R92, R93, R99, R100, R101, R103, R104, R107, R111, R112, R113, R114, R115, R119, R123, R124, R125, R127, R128, R130: 10k; R_0603_1608Metric; JLCPCB C238881
R14: 330R; R_0603_1608Metric; JLCPCB C101062
R15: 3k; R_0603_1608Metric; JLCPCB C126358
R16: 1.2k; R_0603_1608Metric; JLCPCB C269704
R17: 1k; R_0603_1608Metric; JLCPCB C269704
R23: 1k_NC; R_0603_1608Metric; JLCPCB C269704
R33, R47: 10k_NC; R_0603_1608Metric; JLCPCB C238881
R69, R70: 680R; R_0603_1608Metric; JLCPCB C269704
RV1: 07D270K; RV_Disc_D7mm_W3.5mm_P5mm; JLCPCB C317745
SW1: SW_Push; SW_PUSH_6mm_H13mm
U1, U3, U6, U7, U8, U9, U10, U11, U12, U13, U14, U15, U16, U18, U19, U20, U21, U22, U23, U24, U25, U26, U27, U28, U29, U30, U31, U33, U34, U35, U36, U37, U38, U39, U40, U41, U42, U43, U44, U45, U46, U47, U48, U49, U50, U51, U52, U53, U54, U55, U56, U57, U58, U59, U60, U61, U62, U63: PC817X2NIP0F; SOT254P975X400-4N; JLCPCB C6649
U2: LM2596S-ADJ; TO-263-5_TabPin3
U4: AMS1117-3.3; SOT-223-3_TabPin2
U5: DS1307Z+; SOIC-8_3.9x4.9mm_P1.27mm; JLCPCB C26858
U17: RS485; RS485_moduleTTL
U32: P82B96; SO-8_3.9x4.9mm_P1.27mm; JLCPCB C32103
Y1: 32,788 MHz; Crystal_C26-LF_D2.1mm_L6.5mm_Horizontal

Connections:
+3V3: C6.1, C31.1, D1.1 (K), J5.2, J10.5, J17.1, R1.1, R2.1, R3.1, R5.1, R17.1, R24.1, R25.1, R27.2, R28.2, R29.2, R30.2, R31.2, R32.2, R33.2, R41.2, R42.2, R43.2, R44.2, R45.2, R46.2, R47.2, R55.2, R56.2, R57.2, R58.2, R59.2, R60.2, R61.2, R69.1, R70.1, R71.1, R72.1, R73.2, R74.2, R75.2, R76.2, R77.2, R79.2, R80.2, R87.2, R88.2, R89.2, R91.2, R92.2, R93.2, R99.2, R100.2, R101.2, R103.2, R104.2, R107.2, R111.2, R112.2, R113.2, R114.2, R115.2, R119.2, R123.2, R124.2, R125.2, R127.2, R128.2, R130.2, U4.2 (VO), U17.1 (VDD), U32.8 (VCC)
+5V: C1.1, C5.1, C7.1, C8.1, F2.2, J5.1, J10.3, JP1.2, L2.2, R4.1, R6.1, R7.1, R10.1, R15.1, R16.1, R26.1, U4.3 (VI), U5.8 (VCC)
+24V: C2.1, C3.1, D2.1 (K), J10.1, Q5.2 (E), R18.1, R21.1, U2.1 (VIN), U7.3
+48V: J1.2, Q3.2 (E), R8.1, R11.1, R12.1, R20.1, U1.3
A+: J5.6, U17.5 (+A)
B-: J5.7, U17.6 (-B)
Earth: C2.2, C3.2, C8.2, D3.2 (A), D4.1 (K), J15.2, L1.1, R23.2, RV1.2, U2.3 (GND), U2.5 (~ON~/OFF)
GND: BT1.2 (-), C1.2, C4.2, C6.2, C7.2, C9.2, C10.2, C11.2, C12.2, C13.2, C14.2, C15.2, C16.2, C17.2, C18.2, C19.2, C20.2, C21.2, C22.2, C23.2, C24.2, C25.2, C26.2, C27.2, C28.2, C29.2, C30.2, C31.2, C32.2, C33.2, C34.2, C35.2, C36.2, C37.2, C38.2, C39.2, C40.2, C41.2, C42.2, C43.2, C44.2, C45.2, C46.2, C47.2, C48.2, C49.2, C50.2, C51.2, C52.2, C53.2, C54.2, C55.2, C56.2, C57.2, C58.2, C59.2, C60.2, C61.2, C62.2, D5.1 (K), D6.2 (A), D7.3, J3.1, J3.2, J3.43, J3.44, J3.45, J3.46, J4.1, J4.2, J5.3, J10.2, J10.4, J10.6, J17.2, L1.2, Q4.2 (E), R14.2, U3.3, U4.1 (GND), U5.4 (GND), U7.2, U8.3, U9.2, U9.3, U10.3, U11.3, U12.3, U13.3, U14.3, U15.3, U16.3, U17.4 (GND), U18.3, U19.3, U20.3, U21.3, U22.3, U23.3, U24.3, U25.3, U26.3, U27.3, U28.3, U29.3, U30.3, U31.3, U32.4 (GND), U33.3, U34.3, U35.3, U36.3, U37.3, U38.3, U39.3, U40.3, U41.3, U42.3, U43.3, U44.3, U45.3, U46.3, U47.3, U48.3, U49.3, U50.3, U51.3, U52.3, U53.3, U54.3, U55.3, U56.3, U57.3, U58.3, U59.3, U60.3, U61.3, U62.3, U63.3
GND1: J1.1, Q1.2 (E), U1.2, U3.2, U6.2, U6.3, U8.2
GND2: J5.8, U17.7 (GNDD)
GNDA: Q1.3 (C), Q4.3 (C), U10.2, U11.2, U12.2, U13.2, U14.2, U15.2, U16.2, U18.2, U19.2, U20.2, U21.2, U22.2, U23.2, U24.2, U25.2, U26.2, U27.2, U28.2, U29.2, U30.2, U31.2, U33.2, U34.2, U35.2, U36.2, U37.2, U38.2, U39.2, U40.2, U41.2, U42.2, U43.2, U44.2, U45.2, U46.2, U47.2, U48.2, U49.2, U50.2, U51.2, U52.2, U53.2, U54.2, U55.2, U56.2, U57.2, U58.2, U59.2, U60.2, U61.2, U62.2, U63.2
GND_ADC: J3.34, J16.2
unnamed: BT1.1 (+), U5.3 (VBAT)
unnamed: C5.2, JP1.1, R15.2, R23.1, U2.4 (FB)
unnamed: C9.1, D6.1 (K), F2.1, J3.5, J3.6
unnamed: D2.2 (A), F1.1, RV1.1
unnamed: D3.1 (K), L2.1, U2.2 (OUT)
unnamed: D4.2 (A), R16.2
unnamed: D5.2 (A), R17.2
unnamed: J3.3, J3.4, R1.2
unnamed: Q1.1 (B), R9.2
unnamed: Q2.1 (G), R3.2
unnamed: Q3.1 (B), R13.2
unnamed: Q4.1 (B), R19.2
unnamed: Q5.1 (B), R22.2
unnamed: Q6.1 (G), R25.2
unnamed: R8.2, U1.1
unnamed: R9.1, U1.4
unnamed: R10.2, U5.7 (SQW/OUT)
unnamed: R11.2, U3.1
unnamed: R12.2, U6.1
unnamed: R13.1, U6.4
unnamed: R14.1, SW1.1
unnamed: R18.2, U3.4, U7.1
unnamed: R19.1, U7.4
unnamed: R20.2, U8.1
unnamed: R21.2, U8.4, U9.1
unnamed: R22.1, U9.4
unnamed: R34.1, U10.1
unnamed: R35.1, U11.1
unnamed: R36.1, U12.1
unnamed: R37.1, U13.1
unnamed: R38.1, U14.1
unnamed: R39.1, U15.1
unnamed: R40.1, U16.1
unnamed: R48.1, U18.1
unnamed: R49.1, U19.1
unnamed: R50.1, U20.1
unnamed: R51.1, U21.1
unnamed: R52.1, U22.1
unnamed: R53.1, U23.1
unnamed: R54.1, U24.1
unnamed: R62.1, U25.1
unnamed: R63.1, U26.1
unnamed: R64.1, U27.1
unnamed: R65.1, U28.1
unnamed: R66.1, U29.1
unnamed: R67.1, U30.1
unnamed: R68.1, U31.1
unnamed: R78.1, U33.1
unnamed: R81.1, U34.1
unnamed: R82.1, U35.1
unnamed: R83.1, U36.1
unnamed: R84.1, U37.1
unnamed: R85.1, U38.1
unnamed: R86.1, U39.1
unnamed: R90.1, U40.1
unnamed: R94.1, U41.1
unnamed: R95.1, U42.1
unnamed: R96.1, U43.1
unnamed: R97.1, U44.1
unnamed: R98.1, U45.1
unnamed: R102.1, U46.1
unnamed: R105.1, U47.1
unnamed: R106.1, U48.1
unnamed: R108.1, U49.1
unnamed: R109.1, U50.1
unnamed: R110.1, U51.1
unnamed: R116.1, U52.1
unnamed: R117.1, U53.1
unnamed: R118.1, U54.1
unnamed: R120.1, U55.1
unnamed: R121.1, U56.1
unnamed: R122.1, U57.1
unnamed: R126.1, U58.1
unnamed: R129.1, U59.1
unnamed: R131.1, U60.1
unnamed: R132.1, U61.1
unnamed: R133.1, U62.1
unnamed: R134.1, U63.1
unnamed: U5.1 (X1), Y1.1
unnamed: U5.2 (X2), Y1.2
P8.07: C17.1, J4.7, R41.1, U18.4
P8.07_OUT: J11.4, R48.2
P8.08: C10.1, J4.8, R27.1, U10.4
P8.08_OUT: J11.3, R34.2
P8.09: C59.1, J4.9, R125.1, U60.4
P8.09_OUT: J11.2, R131.2
P8.10: C52.1, J4.10, R112.1, U53.4
P8.10_OUT: J14.8, R117.2
P8.11: C45.1, J4.11, R99.1, U46.4
P8.11_OUT: J14.7, R102.2
P8.12: C40.1, J4.12, R88.1, U41.4
P8.12_OUT: J14.6, R94.2
P8.13: C34.1, J4.13, R75.1, U35.4
P8.13_OUT: J14.5, R82.2
P8.14: C26.1, J4.14, R57.1, U27.4
P8.14_OUT: J14.4, R64.2
P8.15: C22.1, J4.15, R45.1, U23.4
P8.15_OUT: J14.3, R53.2
P8.16: C15.1, J4.16, R32.1, U15.4
P8.16_OUT: J14.2, R39.2
P8.17: C62.1, J4.17, R130.1, U63.4
P8.17_OUT: J13.8, R134.2
P8.18: C56.1, J4.18, R119.1, U57.4
P8.18_OUT: J13.7, R122.2
P8.19: C50.1, J4.19, R107.1, U51.4
P8.19_OUT: J13.6, R110.2
P8.26: C44.1, J4.26, R93.1, U45.4
P8.26_OUT: J13.5, R98.2
P8.27: C36.1, J4.27, R77.1, U37.4
P8.27_OUT: J13.4, R84.2
P8.28: C28.1, J4.28, R59.1, U29.4
P8.28_OUT: J13.3, R66.2
P8.29: C19.1, J4.29, R43.1, U20.4
P8.29_OUT: J13.2, R50.2
P8.30: C14.1, J4.30, R31.1, U14.4
P8.30_OUT: J12.8, R38.2
P8.31: C61.1, J4.31, R128.1, U62.4
P8.31_OUT: J12.7, R133.2
P8.32: C55.1, J4.32, R115.1, U56.4
P8.32_OUT: J12.6, R121.2
P8.33: C49.1, J4.33, R104.1, U50.4
P8.33_OUT: J12.5, R109.2
P8.34: C43.1, J4.34, R92.1, U44.4
P8.34_OUT: J12.4, R97.2
P8.35: C38.1, J4.35, R80.1, U39.4
P8.35_OUT: J12.3, R86.2
P8.36: C30.1, J4.36, R61.1, U31.4
P8.36_OUT: J12.2, R68.2
P8.37: C21.1, J4.37, R44.1, U22.4
P8.37_OUT: J7.8, R52.2
P8.38: C13.1, J4.38, R30.1, U13.4
P8.38_OUT: J7.7, R37.2
P8.39: C60.1, J4.39, R127.1, U61.4
P8.39_OUT: J7.6, R132.2
P8.40: C54.1, J4.40, R114.1, U55.4
P8.40_OUT: J7.5, R120.2
P8.41: C48.1, J4.41, R103.1, U49.4
P8.41_OUT: J7.4, R108.2
P8.42: C42.1, J4.42, R91.1, U43.4
P8.42_OUT: J7.3, R96.2
P8.43: C37.1, J4.43, R79.1, U38.4
P8.43_OUT: J7.2, R85.2
P8.44: C29.1, J4.44, R60.1, U30.4
P8.44_OUT: J6.8, R67.2
P8.45: C20.1, J4.45, R47.1, U21.4
P8.45_OUT: J6.7, R51.2
P8.46: C16.1, J4.46, R33.1, U16.4
P8.46_OUT: J6.6, R40.2
P9.11: C24.1, J3.11, R55.1, U25.4
P9.11_OUT: J9.2, R62.2
P9.12: C32.1, J3.12, R73.1, U33.4
P9.12_OUT: J9.3, R78.2
P9.13: C39.1, J3.13, R87.1, U40.4
P9.13_OUT: J9.4, R90.2
P9.14: C46.1, J3.14, R100.1, U47.4
P9.14_OUT: J9.5, R105.2
P9.15: C53.1, J3.15, R113.1, U54.4
P9.15_OUT: J9.6, R118.2
P9.16: C58.1, J3.16, R124.1, U59.4
P9.16_OUT: J9.7, R129.2
P9.17: C11.1, J3.17, R28.1, U11.4
P9.17_OUT: J9.8, R35.2
P9.18: C23.1, J3.18, R46.1, U24.4
P9.18_OUT: J8.2, R54.2
P9.21: C27.1, J3.21, R58.1, U28.4
P9.21_OUT: J8.3, R65.2
P9.22: C35.1, J3.22, R76.1, U36.4
P9.22_OUT: J8.4, R83.2
P9.23: C41.1, J3.23, R89.1, U42.4
P9.23_OUT: J8.5, R95.2
P9.25: C47.1, J3.25, R101.1, U48.4
P9.25_OUT: J8.6, R106.2
P9.27: C51.1, J3.27, R111.1, U52.4
P9.27_OUT: J8.7, R116.2
P9.28: C57.1, J3.28, R123.1, U58.4
P9.28_OUT: J8.8, R126.2
P9.29: C12.1, J3.29, R29.1, U12.4
P9.29_OUT: J6.2, R36.2
P9.30: C18.1, J3.30, R42.1, U19.4
P9.30_OUT: J6.3, R49.2
P9.31: C25.1, J3.31, R56.1, U26.4
P9.31_OUT: J6.4, R63.2
P9.33: J2.7, J3.33
P9.35: J2.5, J3.35
P9.36: J2.6, J3.36
P9.37: J2.3, J3.37
P9.38: J2.4, J3.38
P9.39: J2.1, J3.39
P9.40: J2.2, J3.40
P9.41: C4.1, D1.2 (A), J3.41, R5.2, SW1.2
P9.42: C33.1, J3.42, R74.1, U34.4
P9.42_OUT: J6.5, R81.2
RX: J3.26, U17.3 (RXD)
SCL: J3.19, J10.7, J17.3, Q6.2 (S), R24.2, R71.2, U32.7 (SCL)
SCL_5V: Q6.3 (D), R7.2, R26.2, U5.6 (SCL)
SCL_OUT: D7.1, J5.5, R69.2, U32.5 (TXD-SCL), U32.6 (RXD-SCL)
SDA: J3.20, J10.8, J17.4, Q2.2 (S), R2.2, R72.2, U32.1 (SDA)
SDA_5V: Q2.3 (D), R4.2, R6.2, U5.5 (SDA)
SDA_OUT: D7.2, J5.4, R70.2, U32.2 (RXD-SDA), U32.3 (TXD-SDA)
TX: J3.24, U17.2 (TXD)
VCC: F1.2, J15.1
VDD: J6.1, J7.1, J8.1, J9.1, J11.1, J12.1, J13.1, J14.1, Q3.3 (C), Q5.3 (C)
VDD_ADC: J3.32, J16.1

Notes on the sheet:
Power Supply
I2C
Switch
BeagleBone Black
RS485
Pin Out
Transoptors
ADC
Pinout RS485 and I2C
Pin Down Relay
Automatic PSU Switch
Input Board v0.3 BBB
Clock RTC
Logic Level Converter



Board: 2 copper layers, 256.0 x 74.0 mm, 298 parts (3 on the bottom side), 215 nets.

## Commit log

2021-11-15 Poprawiono gold piny, dodano .stp przekładek między płytkami
    [boneIO-button-distance-relay-24x16A.stp, boneIO-button-distance-relay-32x5A.stp]
2021-11-18 Correction of a schematic error and repair of 3d models
    [CR1220_VCNK.stp, FUSE LTL-451.stp, PC817.STEP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]
2021-11-18 switch to YAML config
2021-11-19 correcting the scheme
    [B2424S-1WR2.step, EDI2CAP.CFG, HF46F.step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]
2021-11-19 cleaning folders
    [boneIOs- input board esp.sch]
2021-11-24 24x16 cleanup
    [PH80DS-21.stp, RM852011351005_1.step, boneIO - relay board.kicad_pcb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]
2021-11-25 Relay model fixed
    [boneIO - relay board.kicad_pcb]
2021-12-04 24x16 v0.3
    [SO8.STEP, boneIO - relay board.kicad_pcb, boneIO - relay board.sch]
2021-12-04 32x5 v0.3
    [HF46F.step, PH80DS-21.stp, SO8.STEP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]
2021-12-04 relay board v0.3 and some cleanup
    [46_pin.stp, boneIO_input board.kicad_pcb, boneIO_input board.sch]
2021-12-05 add support for YAML config, YAML include, I2C, MCP23017, OLED display, stats display.
2021-12-07 Minor fixes, v0.3 electronic assembly in step file, stl files for all parts
    [boneIO-bottom-clips.stl, boneIO-button-distance-relay-24x16A.stp, boneIO-button-distance-relay-32x5A.stp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]
2021-12-07 add LM75 sensor
2021-12-07 fix sensor module
2021-12-08 add exception handling, fix no sensor,oled configured.
2021-12-09 add gpio as sensor pressed,released
2021-12-09 Add files via upload
    Poprawione
    [boneIO - SSR DIMMER.kicad_pcb]
2021-12-10 ADC support, more examples
2021-12-10 add adc schema
2021-12-11 Some minor fixes
    - added external voltage regulator for 3.3V
    - changed names of connectors to be the same as in v0.2
    [boneIO_input board-B_Cu.gbr, boneIO_input board-B_Mask.gbr, boneIO_input board-B_Paste.gbr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]
2021-12-11 Add files via upload
    Poprawione według wskazówek. Wszystkie elementy z jednej strony. Wzmocnione ścieżki HV. Poprawiona numeracja płyty.
    [boneIO - SSR DIMMER.kicad_pcb]
2021-12-11 Added vents on top and bottom and some other minor improvements
    [boneIO-case-front.stl, boneIO-case_front.stl]
2021-12-12 Add files via upload
    Przesunięte triaki i warystory.
    [boneIO - SSR DIMMER.kicad_pcb]
2021-12-13 Add files via upload
    Jumpery po stronie bottom.
    [boneIO - SSR DIMMER.kicad_pcb]
2021-12-14 new pcb 24x10A
    [PH80DS-21.stp, RM852011351005_1.step, SO8.STEP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]
2021-12-18 update input_board_BBB v0.3
    update input_board_BBB v0.3
    [46_pin.stp, CR1220_VCNK.stp, FUSE LTL-451.stp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]
2021-12-18 corrected version
    [boneIO_input board_BBB.kicad_pcb, boneIO_input board_BBB.sch]
2021-12-18 corrected numbering
    [boneIO_input board_BBB.kicad_pcb, boneIO_input board_BBB.sch]
2021-12-18 removal of gerberas
    [boneIO_input board-B_Cu.gbr, boneIO_input board-B_Mask.gbr, boneIO_input board-B_Paste.gbr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]
2021-12-18 corrected J14
    [boneIO_input board_BBB.kicad_pcb]
2021-12-18 Removed folder without BBB suffix
    [46_pin.stp, CR1220_VCNK.stp, FUSE LTL-451.stp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]
2021-12-18 Changed place of K labels
    [boneIO - relay board.kicad_pcb]
2021-12-18 Update boneIO - relay board 32x5A.kicad_pcb
    [boneIO - relay board 32x5A.kicad_pcb]
2021-12-19 Moved some labels
    [boneIO - relay board.kicad_pcb]
2021-12-19 boneIO - shutter board 32x10A
    [PH80DS-21.stp, Relay_SPDT_SANYOU_SRD_Series_Form_C.step, SO8.STEP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]
2021-12-19 Added no connection flags to schema
    [boneIO - shutter board 32x10A.sch]
2021-12-19 Poprawiana wersja
    [boneIO - SSR DIMMER.kicad_pcb]
2021-12-19 Automatic PSU Switch v0.2
    [PC817.STEP, shield input board v0.2.kicad_pcb, shield input board v0.2.sch]
2021-12-19 reduced PCB
    [shield input board v0.2.kicad_pcb]
2021-12-19 New PCB
    [Connector_1Port_RJ45.step, ESP32.STEP, FUSE.stp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]
2021-12-22 Delete Circuit/boneIO - input board_ESP directory
    Not ready for orders
    [Connector_1Port_RJ45.step, ESP32.STEP, FUSE.stp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]
2021-12-29 boneIO v0.3 final case with electronic assembly
    [boneIO-bottom-clips.stl, boneIO-button.stl, boneIO-case-front.stl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]
2022-01-17 Moved case, circuit and code into separate repositories
    [46_pin.stp, CR1220_VCNK.stp, FUSE LTL-451.stp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]
2022-06-20 add sponsor button

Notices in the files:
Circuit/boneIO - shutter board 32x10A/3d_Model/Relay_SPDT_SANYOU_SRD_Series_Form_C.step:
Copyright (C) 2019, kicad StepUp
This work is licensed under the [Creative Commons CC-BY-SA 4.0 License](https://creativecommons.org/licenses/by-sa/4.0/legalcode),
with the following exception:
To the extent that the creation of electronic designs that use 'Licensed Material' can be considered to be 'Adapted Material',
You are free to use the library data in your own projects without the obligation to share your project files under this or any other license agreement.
